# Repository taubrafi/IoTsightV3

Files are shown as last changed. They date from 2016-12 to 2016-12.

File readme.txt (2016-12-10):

IoTSights Project:
	
	Case --Solidworks files for enclosure

	CC3200_workspace
		{Lots of files}	--	Lots of test/old stuff
		ProjectV3 		-- 	main project files
			ADXL345		--Code for accelerometer (interrupt never implemented)
			DS2401		--Code for hardware ID chip
			GPS			--Turn GPS on and off
			HMC5883		--Code for compass (with callibration)
			IMU			--Math to calculate orientation angles
			main		--main
			MPL115A2	--Code to read form barometer and convers to kPa
			NetworkFunctions	--HTTP/Server functions
			NMEA				--Code to decode the GPS information
			parameters			--a few defines and paramaters
			pinmux2 (pinmux ignored)	--pin setup
			SD_card						--Code to write to SD card (not implemented fully)
			SimpleLinkFunctions			--Code to connect to Wi-Fi network 

	OLD project files 	-- report/presentation documentation
		
	PCB					-- PCB files (eagle)
	
	IoT_Sight_FULL 		-- Full schematic for PCB (pdf)

To get up and running:
	Install the latest version of CCS according to the TI website for the CC3200.
	Install Uniflash CC3200_sdk and servicepack (all folowing TI directions exactly)
	See:		https://www.youtube.com/watch?v=xbh9I8waq5g
	Or search: 	"SimpleLink Wi-Fi CC3200 Project 0: Code Composer Studio IDE"

You're ready to go

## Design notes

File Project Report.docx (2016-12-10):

Cover page….

# Abstract

The problem of relaying battlefield information is at the heart of all modern warfare, getting crucial, reliable data from one area to another, or from the battlefield back to the chain of command as fast as possible.

To help mitigate the problem, we developed a small, lightweight, gun mountable sensor array with wireless capabilities and sufficient battery life to record and transmit vital information off the battlefield. In addition, an off-site server will process and display the information, and could be used to alert necessary personnel if need be. The system could also play a role off the battlefield, simplifying the tracking of weapons, automatically calling for backup in sudden life-threatening situations, or to assist training exercises.

# תקציר

בעיית העברת מידע אמין משדה הקרב היא בעיה מרכזית בשדה הקרב המודרני, העברת מידע אמין וחיוני מאזור קרבות אחד למשנהו, או משדה הקרב חזרה לשרשרת הפיקוד במהירות האפשרית. כדי לנסות ולמזער את הבעיה פיתחנו חיישן קטן מימדים וקל משקל להתקנה על הנשק, בעל יכולות אלחוטיות וחיי סוללה מספקים על מנת להקליט ולשדר מידע חיוני משדה הקרב. בנוסף לכך, שרת הנמצא מחוץ לאזור הקרבות יעבד ויציג את המידע המתקבל ויכול לשמש להתרעת כוחות שונים במידת הצורך. בנוסף לכך יכולה מערכת זו לבוא לידי שימוש גם מחוץ לשדה הקרב, לפשט את המעקב אחרי נשקים, הזעקת גיבוי באופן אוטומטי במצבים של סיכון חיים, או לסייע באימונים.

# Table of Contents

# Table of figures

This needs to be updated manually after adding images with captions. Under references->Update table: Ctrl+A F9

# Table of symbols and abbreviations

GPS – Global Positioning System

GLONASS – Global Navigation Satellite System (Russian GPS system)

Li-ion – Lithium ion battery

Wi-Fi – Wireless fidelity (wireless network connection)

PCB – Printed Circuit Board

RF – Radio Frequency

MCU – Microcontroller unit

SPI – Serial peripheral interface

IC – Integrated circuit

I²C – Inter-Integrated circuit communication protocol

SMD – surface mount device

LGA – Land grid array

BGA – Ball grid array

I/O – Input and output

MEMS – Micro-electrical-mechanical system

VCC – Supply voltage

GND – Ground (voltage return)

PLA – Polylactic acid (a plastic)

TI – Texas Instruments

ATM – Automatic teller machine

AWS – amazon web services

ec2 – elastic cloud computing

HTTP – hypertext transfer protocol

SSH – secure shell

OS – operating system

# 1 Introduction

## 1.1 System purpose

The system consists of two separate sections, a physical unit, distributed to each soldier and mounted to the weapon, and a server to collect and process the data.

The unit is always running, but remains dormant most of the time to conserve battery life. When a soldier fires his weapon, the weapon experiences a sudden change in acceleration along its axis, known as ‘recoil’. The device’s accelerometer captures this sudden change in acceleration and causes an interrupt to wake up the processor. The processor then takes a snapshot of all current sensor data and preprocesses it to extract the devices orientation, heading, altitude and position, and the time of the occurrence. This information, along with the devices unique ID number, is sent via Wi-Fi to the main server, which displays the information on an interactive map. Depending on requirements, the server could be setup for multiple purposes. In one instance, it could be used to take multiple shots’ information to predict where enemies might be and automatically notify other soldiers in the area that assistance is necessary. The server could also be setup as part of training exercises, and would be used to analyze how many shots each participant fired and how accurate each shot was. The device could also be mounted to steel plate targets to detect when a ‘hit’ occurred.

## 1.2 Physical Unit

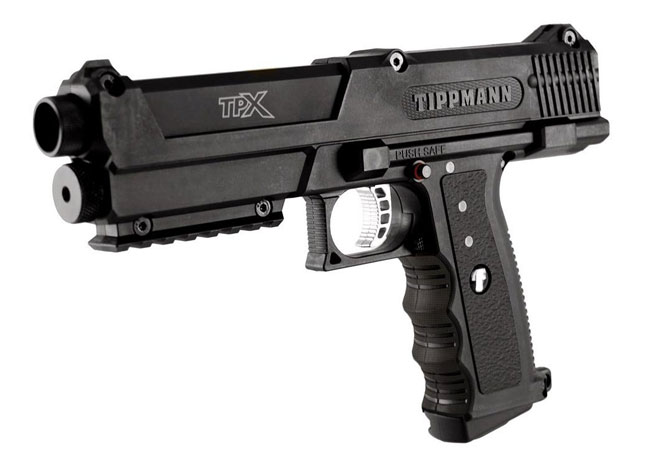
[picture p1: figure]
Image result for picatinny rail paintball

The physical unit is a small plastic enclosure not much bigger than a can of soda and weighing ~???g. It can be mounted to nearly any weapon via a standard ‘Picatinny rail’ mounts which are commonly used for mounting accessories to a weapon such as scope sights, lasers, and flashlights (see Figure 1). These are present on nearly all military issue weapons ranging from pistols to large machine guns.

Figure 1: Picatinny rail on a paintball pistol

The unit is a sensor array consisting of the following:

- Accelerometer
- Gyroscope
- Magnetometer
- Barometer
- GPS receiver

Together, they give the ability to read out orientation, altitude, and location in the form of roll, pitch and yaw angles, GPS coordinates and ambient air pressure. The accelerometer also gives the ability to send out an interrupt on sudden changes in acceleration along any axis, which is used for the shot detection function.

The plastic enclosure houses the battery and main PCB, and can be sealed against water and dust while still providing a pressure relief port to take accurate air pressure measurements.

The battery is a standard sized Li-ion cell, which can be swapped out for charging. The idle battery life is just over 21 days, and each shot detection and transmission taking up to 30 seconds expends the battery life equivalent of up to 6 minutes of idle time.

## 1.3 Server

The server is a virtual machine provided by amazon as part of AWS. In the service, it is often called an instance of ec2. That means that the consumer is provided with a computation power and internet connectivity without having to buy hardware, Thus enabling a low cost server farm to be used while enjoying robustness huge scalability and few locations redundancy for mission critical solutions.

The virtual machine is configured to run Ubuntu a distribution of linux that is used both in commercial and private settings. The http server is apache, it is the means by which the HTTP requests are served so that users could connect to the webpage. The webpage itself has a dynamic rendering that creates an html view according to the queried parameters. The language used to create the dynamic interaction is python, namely the django library of the language. Data from devices is stored in sqlite3. Map rendering is made with a google maps API in javascript. There is also an xml static page served for the devices to read periodicaly to change their state to close a control loop.

xml | Images | Css | javascript | Html
Static files | | Django app
Apache web server | | | sqlite3

Ubuntu linux

AWS amazon cloud compute

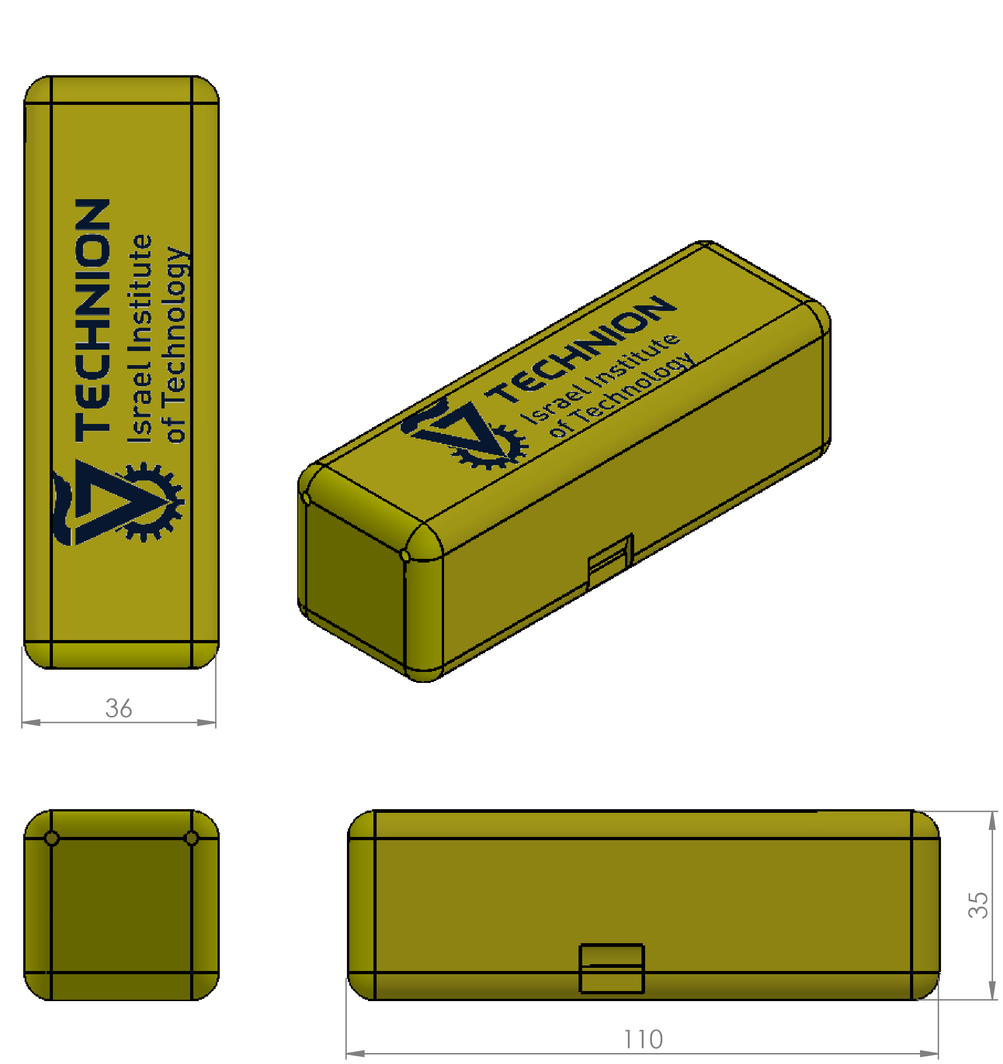
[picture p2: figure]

# 2 Specifications

Figure 2: Device physical dimensions

## 2.1 Physical Specifications

PARAMETER | | UNIT
Length | 110 | mm
Width | 36 | mm
Height | 35 | mm
Weight | 120 | g
Operational Temperature range | -40 to +85 | °C

## 2.2 Electrical specifications

PARAMETER | | UNIT
Battery Type | 18650 Li-ion | -
Battery Voltage | 3.5 to 4.4 | V
Battery Capacity | 2200 | mAh
Idle current | 4.3 | mA
Idle battery life | 21.3 | day
Transmitting current | 54 | mA
Continuous transmission battery life | 40 | hour
Peak current | 250 | mA
Maximum time to transmission | 30 | second
Roll accuracy | ±1.0 | degree
Pitch accuracy | ±1.0 | degree
Heading accuracy | ±2.0 | degree
Position accuracy | 10 | m radius

## 2.3 Server specifications

The server is a t2.micro instance with the following specs:

Vcpus | 1
RAM | 1Gb
HDD | 8Gb
OS | ubuntu

We are using apache2. Python 2.7 . Django 1.9 . slqite3.

# 3 Workflow

## 3.1 Hardware

MCU

[CC3200]

Accelerometer

[ADXL345]

Wi-Fi

[CC3200]

Magnetometer

[HMC5883L]

Gyroscope

[ITG3200]

GPS

[NEO-6M]

SD card

Support Hardware

Figure 3: Hardware block diagram

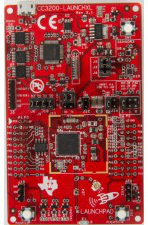
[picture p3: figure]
Image result for cc3200 development kit

### 3.1.1 Component choices

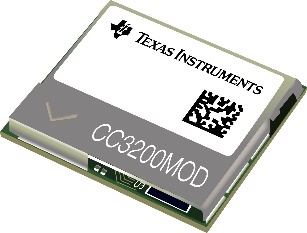
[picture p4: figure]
Image result for cc3200mod

The first major component is the MCU, which serves as the processor for the hardware. For this purpose, the CC3200 chipset from TI was chosen. This was because it has built-in Wi-Fi capabilities which require no external components aside from an antenna. This greatly reduces the amount of design work that falls into the RF spectrum which requires a great deal of additional experience. The CC3200 is available in two forms, the first, a SMD chip, which needs various support components such as decoupling capacitors, pullup resistors, crystal resonators, and an SPI flash memory chip. The second form is a module which has all the above components build into a SMD LGA package of 17.5mm x 20.5mm. Due to cost and ease of use, the chip form was used during development while the module was used on the final PCB. The MCU also feature a hibernate mode where current consumption drops down to 4uA while still allowing for external interrupts to ‘wake up’ the MCU. This choice also eliminates the need for an external wireless chipset which also conserves power since readily available Wi-Fi modules such as the ESP8266 use more power even when in hibernation modes.

Figure 4: CC3200 module

Figure 5: CC3200 development kit

For an accelerometer, the ADXL345 was chosen for its low power consumption, easy to solder package (LGA as opposed to BGA) and its dual configurable interrupt outputs which were used for the ‘shot detection’ feature. The interrupts are configurable to only capture motion along a single axis and to fire only when the acceleration exceeds a configurable magnitude. The data can then be read out over an I²C interface.

The HMC5883L was chosen as the magnetometer the device for the same reasons that it’s very popular in the hobbyist community. It has low power consumption, simple I²C interface, and easy to solder SMD package.

A gyroscope chip, the ITG3200 was also included in the design, although it isn’t necessary for the intended application of the device and the component does not need to be inserted during manufacturing. Its pads however are present on the PCB, which enables various other applications and uses for the device as will be mentioned later.

Because of time constrains and availability, the NEO-6M was chosen as the GPS module for the device, since it was already on hand.

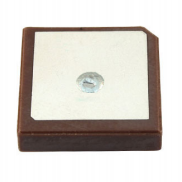
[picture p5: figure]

Since the unit will be oriented in a specific direction and the GPS satellites only ever being above any point on earth, the antenna for the GPS could be a directional antenna, which would provide gain to the GPS signal, and in turn, greater accuracy in position measurements. Since the output impedance of the CC3200 is 50Ω, it was easiest to find an antenna which also had an impedance of 50Ω. In addition, the device required a rather thin profile which lead to the choice of a ceramic patch antenna. The ADA18182 was chosen for this since it is easy to solder and for its small size of 18mm x 18mm and 2mm height.

Figure 6: ADA18182 ceramic patch antenna

Again, due to time constraints and availability the MPL115A was chosen as the barometer for the device to give more accurate altitude measurements than the GPS system can provide. The ‘A2’ version of the chip was used since it interfaces via I²C as the other sensors do and therefor doesn’t require additional I/O pins.

The last major component is the DS2401+ which is a silicon serial number. It provides a unique 64-bit identification number hard coded into the device (which gives 18 billion-billion unique ID numbers). Since no two chips have the same number this enables individual tracking of every device and the ID number can be matched with every issued weapon and individual using it. This device also has a ‘OneWire’ interface which only requires one additional I/O pin. (The chip only has two pins, ground, and data. There is no positive voltage line, instead the chip charges an internal capacitor from the pullup resistor on the data line and uses that stored charge to continue operating when the data line is low.)

In addition to the above, various other components such as capacitors, resistors, LEDs, a transistor, voltage regulator and a microSD card socket were included in the design. The microSD card connector was included for future expandability and as with the gyro, does not play a role in this application.

### 3.1.2 Electrical design (schematic)

The schematic design is rather straightforward, all the integrated circuits were connected with the necessary external components as per the manufacturer’s specifications. In addition, decoupling capacitors were placed near each IC. A removable solder jumper was added between the DAT1 pin of the SD card and GND. This enabled the switching of SD card protocols during the debug stage. In the end, the ‘SPI mode’ of the SD card was chosen, meaning the jumper can be left as is (connected to GND).

To conserve power, a PNP transistor was connected between VCC and the GPS receiver’s main power input pin while the backup battery input was left connected to VCC. This enables the shutdown of the GPS receiver to be controlled by the microcontroller while keeping the GPS data in memory. This ensures a faster ‘hot fix’ when trying to regain the location data from the GPS system.

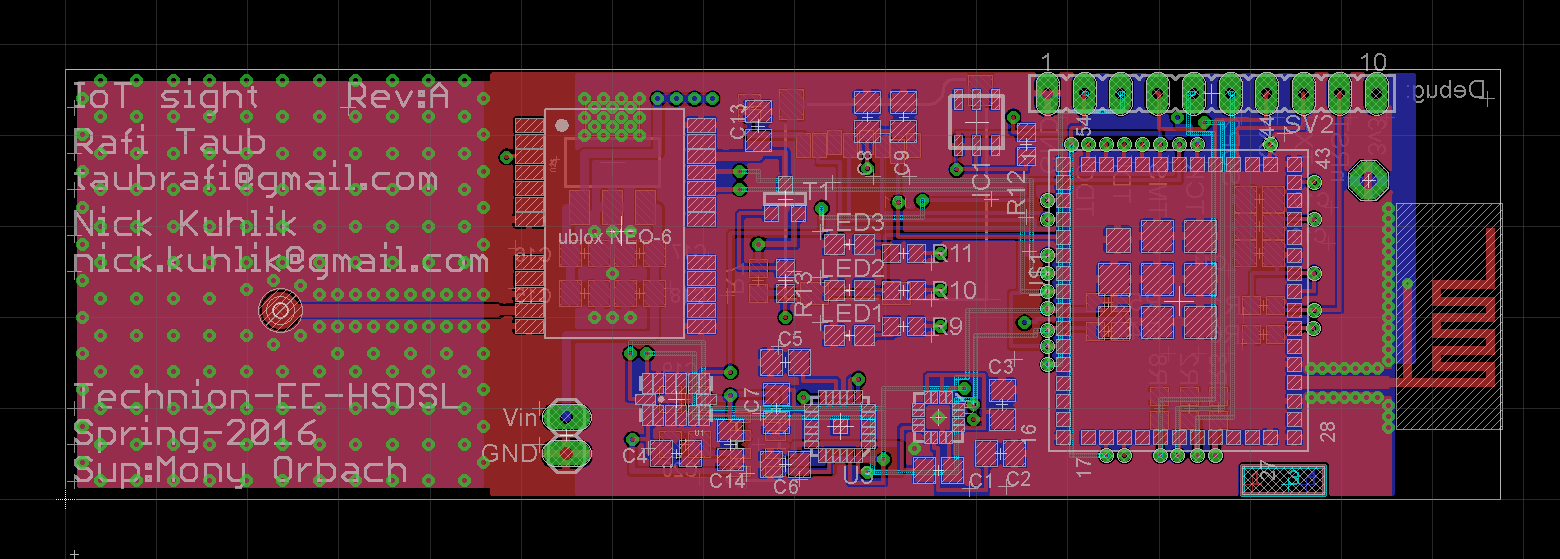
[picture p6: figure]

### 3.1.3 PCB design (layout)

The PCB was designed using EAGLE which is a combined schematic and layout software which is supported by most PCB manufacturers.

The PCB has four layers which are (from top to bottom): Signal layer with ground plane flood, supply voltage plane, signal layer, signal layer with ground plane flood. Although the system performs as expected the two internal layers should have been voltage supply and ground, with all signals kept on the outer layers. This would increase the distributed capacitance across the entire board keeping noise to a minimum. It would also keep a solid ground plane below signal traces keeping impedance constant and minimizing wave propagation artifacts caused by reflections. However, since all signals (excluding the RF areas which have no internal layers) in the device are rather slow (less than 1MHz) we did not experience any issues.

Figure 7: The device PCB in EAGLE

Three LED indicators were added at this stage (as can be seen in the center) and were connected to three spare I/O pins on the CC3200. They were meant as aids during debugging and are not mean to serve any function in the final version. That said, as with the gyro and SD card could be used in possible future applications for the device.

The three MEMS sensors were placed so that all their axes are aligned to keep data processing simple, and a debug header is also present to enable programming of the CPU without the need for desoldering. It also provides a serial terminal for printing debug messages and data (again, for use during debugging). Two battery voltage input pins are also present.

Lastly, ‘open vias’ we placed on all signal pins to enable probing, and cutting-resoldering of traces as needed when working on hardware. To aid in probing, one more large ‘via’ was added and connected to the ground plane as a reference for oscilloscopes and logic analyzers

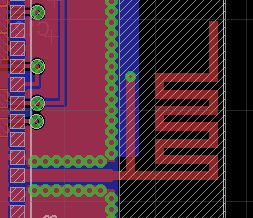
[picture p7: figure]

### 3.1.4 RF and antenna design

The last two key components on the PCB require special attention. The Wi-Fi antenna was designed as part of the board while the GPS antenna is a ceramic patch antenna. Both require specific dimensions in both the traces that connect them and the ground plane below them.

Figure 8:Wi-Fi antenna close-up

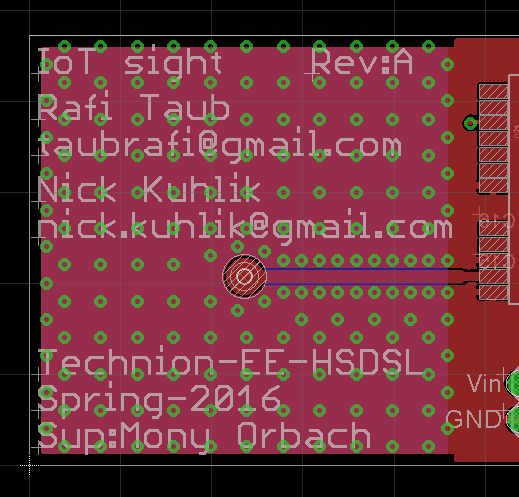
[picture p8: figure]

The design for the Wi-Fi antenna was taken from an application note[^1] from Cypress semiconductors on Wi-Fi and Bluetooth antenna design. The PCB antenna choice was made to since it doesn’t require a matching network to convert to a 50Ω trace. It also provides reasonable directionality, sending the signal out along the plane of the PCB instead of normal to the PCB, which would be directed into the battery. This effectively adds gain to the signal being sent back to the router which is receiving the signal adding range to the unit’s operating radius. In addition, the trace connecting the antenna to the CC3200 is of a specific width with the ground plane coming to a specific distance away from the trace. This trace setup is known as a ‘coplanar wave guide’ and is commonly used for signals in the few up to tens of GHz range.

For the GPS antenna, the dimensions for the ground plane were taken from the device’s datasheet. The ground plane gives then antenna directionality and therefore gain (of about +5dB) in the upward direction normal to the plane of the PCB. This improves positional accuracy, likelihood of GPS lock, and time to lock for the GPS receiver. The trace connecting the GPS antenna to the receiver is also a ‘coplanar wave guide’ and has the same dimensions as the Wi-Fi trace since the GPS signals are in the same band being ~1.5GHz.

Figure 9: GPS test antenna

Figure 10: GPS antenna close-up

During development not all the components had arrived, so for testing a dipole antenna for the GPS was desinged and added as part of the PCB sent to manufacturing. Although it does work, the ciramic antenna is a better choice for its directionality and low losses.

### 3.1.5 Mechanical design

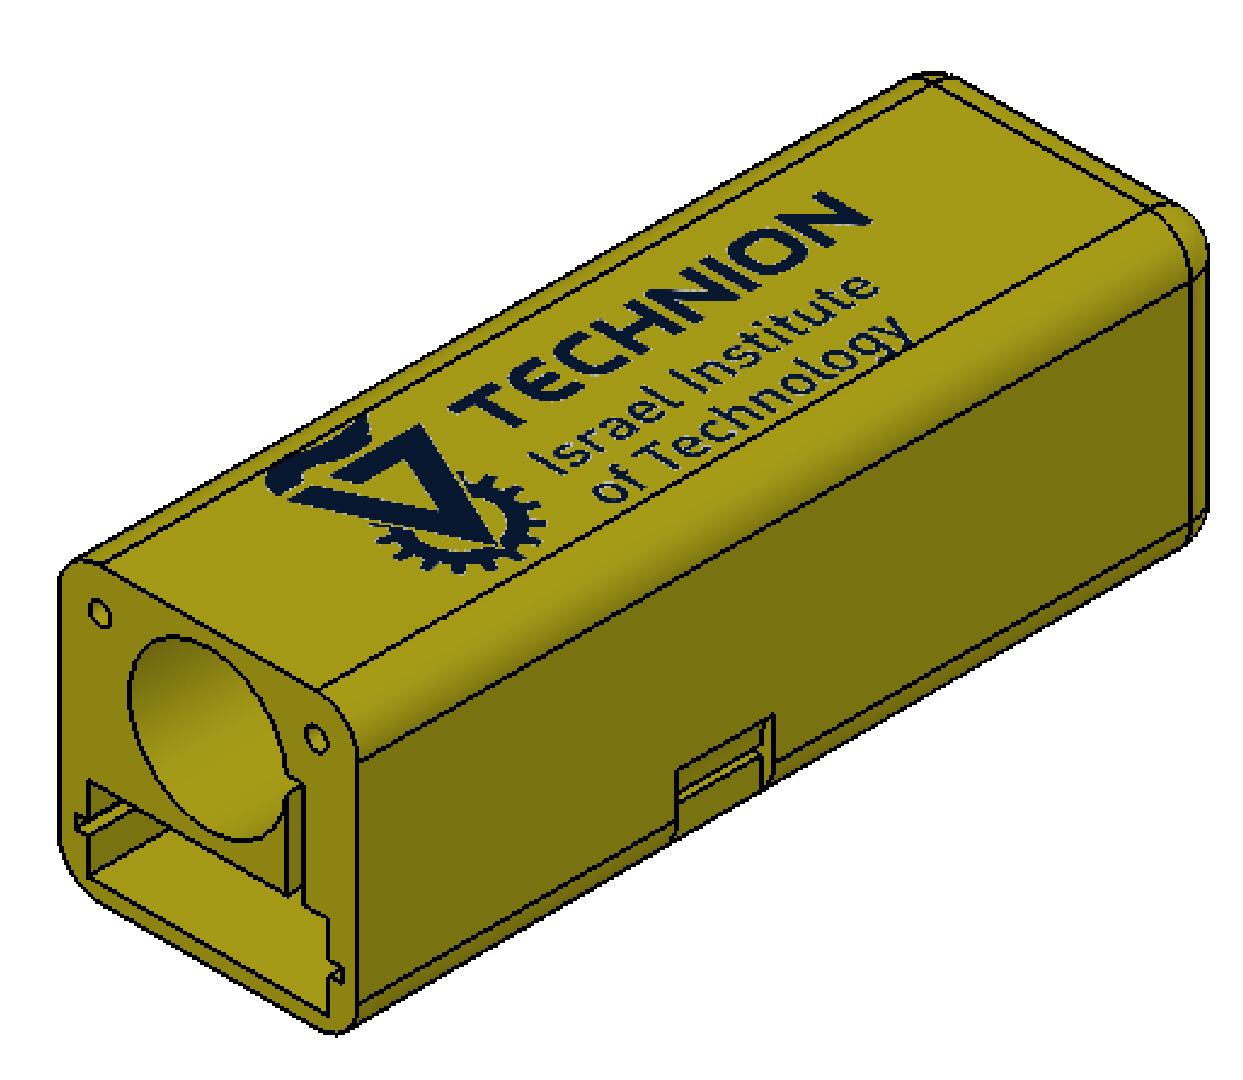
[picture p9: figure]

The devices prototype enclosure is a 3D-printed PLA which was designed in SolidWorks. It features a slot for the PCB and a compartment for the battery. The battery was chosen to be an 18650 Li-ion rechargeable battery with a nominal voltage of 3.7v-4.2v and a capacity of 2200mAh. The slot along the side of the battery cutout is for the wire running to one of the terminals. Both wires run down into the lower compartment to the main PCB. In addition, a slot on the side of the enclosure gives access to the microSD card and lines up with the socket on the PCB. The alignment was maintained by taking measurements from the PCB and bringing them into SolidWorks to make the required cuts. A rubber cap could be designed to cover this hole to provide weatherproofing while still allowing changes in air pressure through to the internal barometer. The cover attaches to the case by two #4-40 screws which rotate freely in the cover and screw into the slightly undersized hole in the main body of the enclosure to ensure a solid connection. The last part of the enclosure not show in this diagram is a mount to connect the device to the Picatinny rail system for mounting on a weapon.

Figure 11: Device enclosure

## 3.2 Firmware

Figure 12: Firmware flowchart

Calibration routines

Sleep

Power on sensors

Read sensor data

Calculate altitude & attitude

Get position from GPS

Power off sensors

Accelerometer triggered interrupt

Send data to server

### 3.2.1 Orientation algorithm

Once a shot is fired the accelerometer triggers an interrupt on the MCU which prompts it to turn on the GPS module and proceed to take readings from the various sensors. From the corrected magnetometer data (B_(fx) ,B_(fy) , B_(fz) ) and the accelerometer data (G_x , G_y , G_z ) .

First the roll angle ϕ is calculated as:

ϕ=atan2(G_y , G_z )

(Note the atan2(y,x) function provides the inverse of tan(⋅)=y/x where the signs of x and y are maintained, giving a result on [-π,π] instead of [-π/2,π/2] .)

Next, the pitch angle θ is calculated as:

θ=atan(-G_x , G_y sinϕ+G_z cosϕ)

(Not atan2(y,x) since the pitch angle should lie on [-π/2,π/2] .)

Lastly, the yaw (heading from magnetic north) angle is calculated as:

ψ=atan2(B_(fz) sinϕ-B_(fy) cosϕ, B_(fx) cosθ+B_(fy) sinθsinϕ+B_(fz) sinθcosϕ )

Together these three angles give a complete description of how the device (and therefore the shooter) is oriented at the time of the occurrence.

### 3.2.2 Magnetometer Calibration

As mentioned, the magnetometer data is used to calculate the orientation angles of the device and the equations rely on the magnetometer data (B_x , B_y , B_z ) however, this data is not usable directly as magnetic offsets are a major problem with magnetometers. Any piece of ferrous metal (steel, iron, etc.) all have slight magnetizations and will offset the magnetometer readings.

If each data reading from the magnetometer were to be plotted on a graph while the device was rotated to every possible orientation, the points would form an ellipsoid with axis lengths of (l_x ,l_y , l_z ) in the x, y and z directions respectively and the center of the ellipsoid would be at (p_x , p_y , p_z ) . Ideally, the center of the ellipsoid would be at (0, 0, 0) and the axis lengths would all be equal (1, 1, 1). However, small magnetized objects will both shift the center of the ellipsoid along the axis the magnetic material points, and lengthen or contract the respective axis depending on the alignment of the material. This could be potentially catastrophic as a flat north-facing orientation, which would ideally give a magnetometer reading of (1,0,0) would be could be shifted and scaled to give any possible reading (a reading of (-1,0,0) would mean south). To counter this, a simple calibration algorithm was added to the software, which works as follows:

- Six static values are stored which represent the lowest and highest recorded values (the ‘extreme values’) on each of the magnetometer’s axis respectively. (X_m , X_M ),(Y_m , Y_M ), (Z_m ,Z_M )
- On each reading, the current value is compared with the stored extreme values, and the extreme values are updated as needed.
- We then define: p_x =(X_m +X_M)/2 , p_y =(Y_m +Y_M)/2, p_z =(Z_m +Z_M)/2 . Since an ellipsoid is symmetric with regards to any of its axes, its center must be halfway between its two ends. Thus, we know where the center of this offset ellipsoid lies.
- Next, we define: l_x =X_M -X_m ,l_y =Y_M -Y_m ,l_x =Z_M -Z_m which represent the lengths of each of the axes of the offset ellipsoid.
- Lastly, B_(fx) =(B_x -p_x)/(l_x), B_(fy) =(B_y -p_y)/(l_y), B_(fz) =(B_z -p_z)/(l_z) This shifts the ellipsoid back to (0, 0, 0) and brings then axis lengths back to (1, 1, 1).

This algorithm is essential in maintaining good orientation data accuracy. One of its main benefits over pre-calibrating each device is that this algorithm is a very simplistic ‘machine learning’ algorithm. To initially calibrate the unit, one simply needs to rotate the unit a few times in each direction, and once mounted to the weapon the offsets would change since the weapon itself contain many metal pieces. Even the bullets or magazines could be magnetic and since they are swapped out regularly, it would mean any possible pre-calibration would be useless. But with this algorithm, one needs to just power cycle the device (by swapping the batteries) and rotate the device while attached to the weapon to recalculate the calibration values.

### 3.2.3 Issues with I²C, Wi-Fi startup and z axis magnetometer data

During the development stage, several interesting issues were uncovered which are worth mentioning since their cause was not due to any development error on our part but rather on the manufacturers of some of the components we used. Two such issues were found in the CC3200 manufactures by Texas Instruments. The CC3200 was a relatively new device at the time when development started and as with many new devices, it had some issues that had not yet been found. The first of which was had to do with the assignment of I/O pins used for I²C communications. To save pins on the device package, the two I²C pins can be mapped to several physical pins on the device, but only two such physical pins can be assigned for this purpose. It turned out the device had a predetermined assignment for these pins which was not noted in the datasheet and the assignment had to be undone before reassignment could be performed. A few weeks after we found the issue, a relevant section was added to the CC3200 errata sheet on TI’s website. A similar issue was found in the startup code for the Wi-Fi communications on the CC3200 and was later corrected with a library update by TI.

The last notable issue was not a software bug but rather a hardware defect. As it turns out, the HMC5883L chips which we purchased for use in the early design stage were not manufactured by Honeywell, but instead were manufactured by some copy facility in china. These ‘copy chips’ were not as robust as the originals and the Z axis sensor head inside the chip would fail and only gave constant data. Once the problem was discovered, some genuine chips were ordered which worked flawlessly.

### 3.2.4 Get request

The very last step in the data path for the device is the ‘Get request’ sent over the Wi-Fi network connection to the server. The request is formatted to have separate fields in a predefined protocol setup for this system and transmits: the current date and time, the devices latitude and longitude, the ambient air pressure (used in conjunction with weather servers to calculate altitude), the device’s orientation angles, and the device’s unique ID number.

# 4 Software (server)

## 4.1 Architecture

xml | Images | Css | javascript | Html
Static files | | Django app
Apache web server | | | sqlite3

Ubuntu linux

AWS amazon cloud compute

The architecture selected for the server was guided by the principles of simplicity, scalability and reliance on free open source software.

By implementing those principles it is guaranteed that the project will be easy to maintain and easily passed to future generations of students. The

TODO:

here goes explanation about the idea to make a mono-core of code that uses python.

Google maps api addition. Since we didn’t want to roll out our own maps.

## 4.2 AWS

The aws platform gives a readily made instance of a computer that can be easily replicated to adjust for demand. The servers are located In data-centers separate from each other thus granting fault tolerance in case of a local disaster that disables one of the locations. Also, it is easier to rent a server on the web and route all traffic to it instead of aquiring a pc to be used in the technion network and having to open up connections to the internet and managing the hardware. A fault that was critical to another project in the HSDL lab.

In conclusion, the aws platform is both convenient for both small scale deployments that don’t necessitate the purchase of additional hardware and large scale mission critical deployments.

## 4.3 Ubuntu

Ubuntu is free open source linux distribution targeted both for the private and corporate use. The distribution is well supported and well documented with a vast community of developers using the OS.

The ubuntu os takes care of the lower levels of the OSI hierarchy registering the pc on the network, creating sockets and collecting ip packets into a tcp protocol.

Also, the ubuntu machine runs the application and saves the database giving useful tools to manage and edit both.

## 4.4 Application

the application is constructed upon the interaction of a database, a collection of static resources that are not need to interact with the server in a dynamic way , and a python application that controls the database workflow, fetches static files, renders dynamic views for the user and interacts with the thin client implemented on the tracked unit.

## 4.5 sqlite3

sqlite is a relational database used to create read update and delete records in a SQL way that makes a standardized way to work with data. This way was chosen because it is easily used, although it may be switched for any preferred database with little effort.

The application generates the needed data tables in accordance to the models that are described in the application code. The data is then easily saved and retrieved and can be accessed both from the python wrapper for sqlite3 and a mysql like command line tool.

The sqlite3 is pointed back to the hosting machine, but in future versions can be shared with several machines hiding behind the DMZ in the internal firewall. This configuration can be useful for decoupling database and apps for robustness and scalability.

## 4.6 Apache*

The apache web server manages connections on the http level, after a connection has been established by the linux os, the http web server must direct the user to the appropriate location and gather the data needed from the application to return.

The apache web server was chosen for its free as in free beer ideology and great swath of support.

## 4.7 django

Django is a full stack web framework written in python that is used to control the layer 7 application interaction with server. The framework is a set of modules written in python that make prototyping websites faster and easier by taking care of the stuff that usually all web servers must preform and giving capabilities to write code that will do the “Buisness Logic” of the application.

The application is created in the mvc design pattern which separates the problem into 3 components.

The central component of MVC, the model, captures the behavior of the application in terms of its problem domain, independent of the user interface.

- The model directly manages the data, logic, and rules of the application.
- A view can be any output representation of information, such as a chart or a diagram. Multiple views of the same information are possible, such as a bar chart for management and a tabular view for accountants.
- The third part, the controller, accepts input and converts it to commands for the model or view.

In our app, the model -represent the shots class and its methods.

The view – is the /shots page that prints the output.

The controller is the url parser that directs the user to the page requested (view) showing the data selected (model).

## 4.8 google maps api

Using the javascript api, the google maps api is useful for visualising the received points of interest and bearings to the user that shall interpret them. It is possible to use javascript additional functionality and create algorithms for crossfire enemy detection based on time and location, friendly fire alarms and training situations in which part of the sensors are designated static targets. Also we can show different slicing of data, by time period or location specific and even create a “recording” of events that shall be useful in debriefing missions or training excercises.

## 4.9 xml gateway

The xml gateway is a useful format to push data back into the tracking device’s memory. Since each unit is arbitrarily woken up and may experience connection loss or be given a dynamic ip, there has to be a way to update the settings that govern the devices. The best way is to point them to a known location available when connection to transmit data has occurred. The xml page contains the id and data settings that need to be parsed by each device. The xml page in the prototype is a dummy place holder and has no receive functionality on the devices (as of writing of this project report it was deemed useless for the means of this configuration). The django app can and should create a the xml file in accordance with the logic decided upon.

## 4.10 server issues at deployment

After creating the application on a local machine, the migration process was to upload the files into an ec2 instance from the github repository.

On the local machine an Internet port serving only the localhost is generated once the app is run. Once the app is deployed a web server (like apache) has to commandeer access to the requested ip and pass them to the app.

In the development process a problem was encountered that only part of the webpage would load without additional styling. Thus giving a plain look to pages that were stylized before the deployment.

Since it was chosen to host the static files locally, the app had to look up the files on the hard disk and send them to the user to generate an HTML. The problem has been diagnosed as a permissions denied response when requesting those static files. A number of fixes to try and change file permissions were tried, changing locations, owners, privileges and such.

The problem was at last solved by a technical document describing the proper apache configuration to enable a static folder to become world available and thus hyperlinked to the HTML file, rendering it completely.

The main takeaway from this problem was that although there is great support for apache, a problem with django which was still young at the time was not identified correctly due to not informative errors and then hard to fix since the django-apache stack was new at the time.Performance tests

# 5 Extensions and additions

This system has many more possible applications that the original intended purpose. The physical unit is essentially just a Wi-Fi connected sensor module with GPS and datalogging which could be used for inventory or vehicle tracking, amateur rocket experiments, long term datalogging, earthquake detection and much more. In addition, the I²C and SPI interfaces, along with the remaining I/O pins could be used to connect further external sensors or as outputs to trigger alarms, lights, motors, or anything else. Combined with the small form factor this device could even serve as the heart of an autonomous drone and could in theory support a low-resolution camera and transmit back over Wi-Fi.

One addition that was left out of the project due to time constraints and practicality is encryption. It wouldn’t be very smart for every soldier to transmit his location over a Wi-Fi connection, since any laptop running Wireshark (a free network traffic analyzer tool) could simply read out the data and track down the soldiers. Therefore, a layer of encryption would be necessary to hid the data from anyone who could try to read it. This encryption would have to be implemented on both ends, the device, and the server, and must be done in such a way that even if a potential enemy gets hold of one of these devices, he still would not be able to break the encryption. Solutions like this are quite common in the software industry and it’s how activating a piece of software with a license key is simple and yet it’s impossible to somehow find out what possible license keys the software would treat as valid even if you have the software installed.

Another feature that could be added to avoid the above issue is a remote self-destruct, where the microcontroller could wipe its own flash memory and reset itself (doing nothing from then on unless reprogramed) if the PCB area of the enclosure is opened or by remote signal (a technique used in cred card readers and ATMs to prevent bank fraud).

# 6 Source code

Device firmware and project files: https://github.com/taubrafi/IoTsightV3

Server source code: https://github.com/sudo-Whateverman/IOTsights

# 7 Appendix

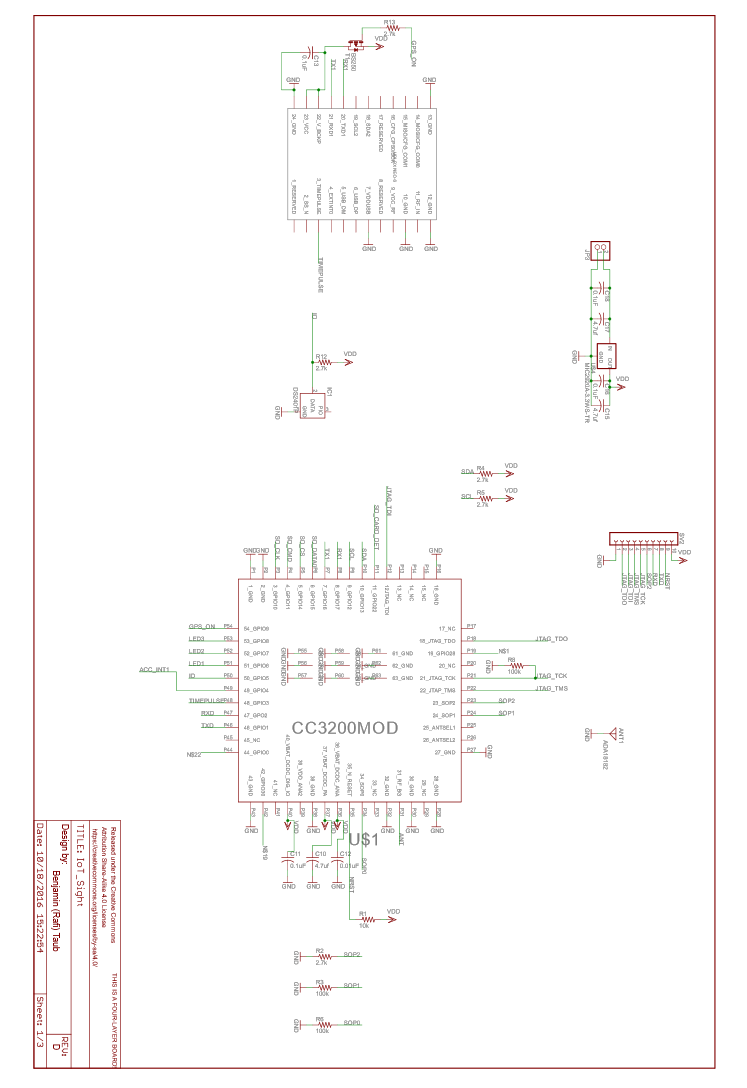
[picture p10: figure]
Machine generated alternative text: GNDGNDGND GND GND GND GND GNDGNDGND GND GND GND GND GNDGND GNDGND 10k 2.7k 100k 100k GNDGNDGND VDD VDD VDD VDD 2.7k 2.7k VDD VDD GND GND GND GNDGND 4.7uf 0.1uF0.01uF GND GND GND 100k GND GND VDD DS2401P GND 2.7k VDD 0.1uF ADA18182 GND MIC2920A-3.3WS-TR VDD GND 4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

## 7.1 Appendix A: Full electrical schematics

Figure 13: Electrical schematic page 1 of 3 (main MCU and GPS)

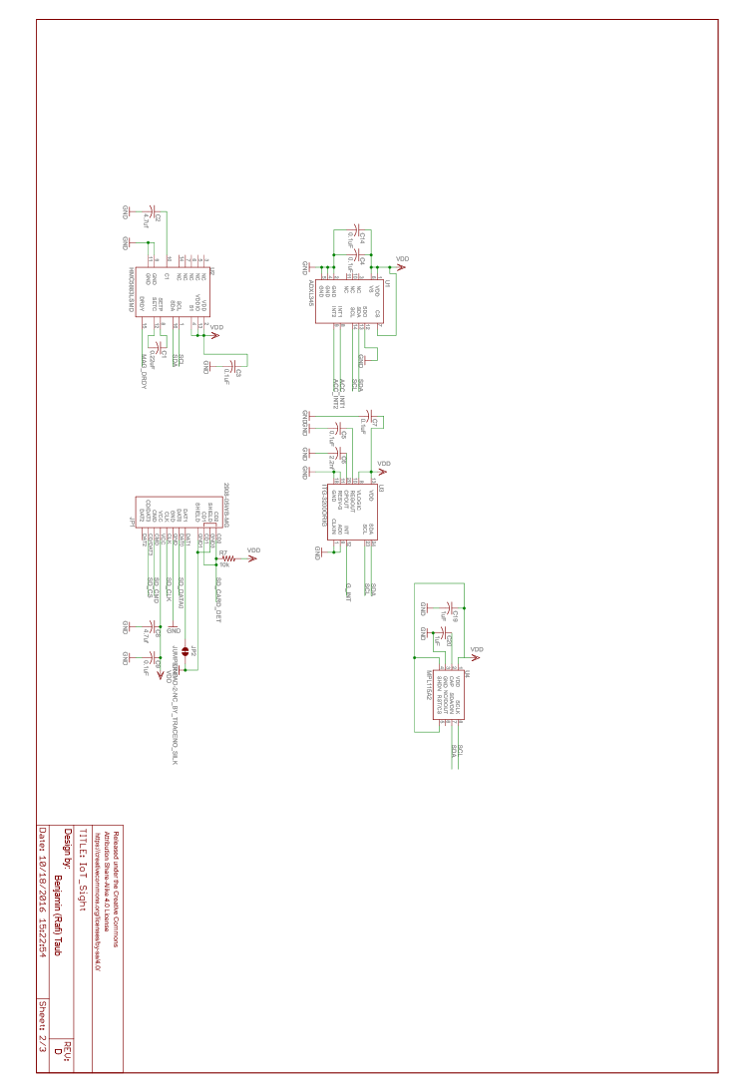
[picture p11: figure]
Machine generated alternative text: ADXL345 HMC5883LSMD ITG-3200ORIG 2908-05WB-MG VDD GND VDD GND GND VDD GND 0.22uF 4.7uf GND 0.1uF GND 0.1uF GND 0.1uF2.2nf 0.1uF JUMPER-PAD-2-NC_BY_TRACENO_SILK GND 10k VDD VDD GND 4.7uf0.1uF GNDGND 0.1uF MPL115A2 1uF 1uF VDD GND GND GND GND GND U1 VDD 1 NC 11 NC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

Figure 14: Electrical schematic page 2 of 3 (sensors and SD card)

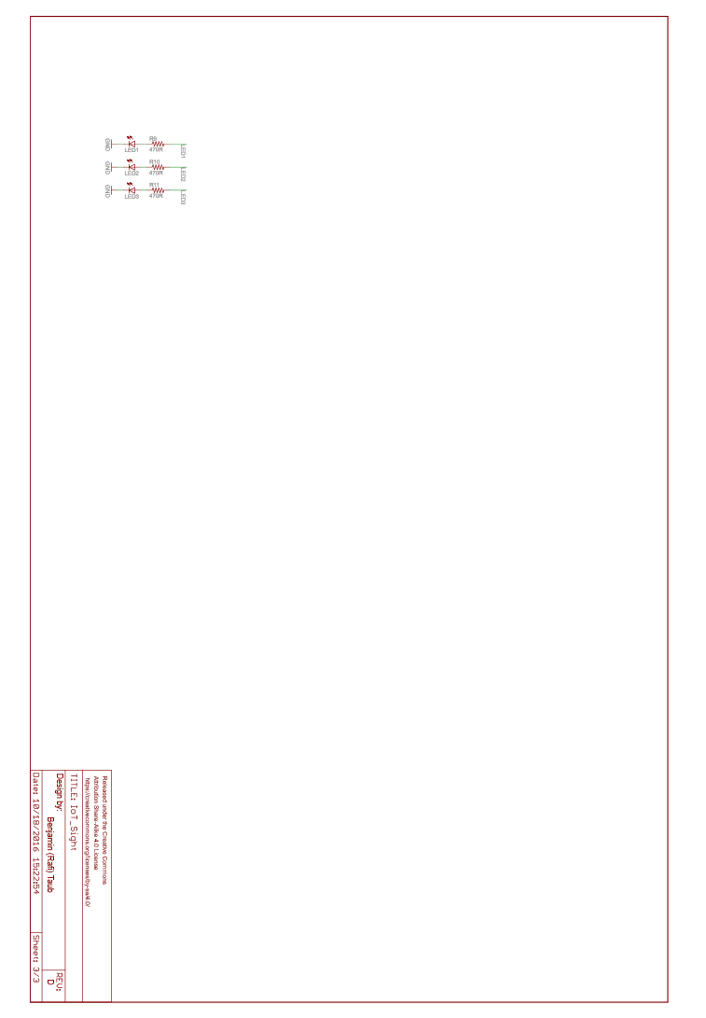
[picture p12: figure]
Machine generated alternative text: 470R 470R 470R GND GNDGND LED1 LED2 LED3 R9 R10 R11 LED1LED2LED3 D Benjamin (Rafi) Taub Released under the Creative Commons Attribution Share-Alike 4.0 License https://creativecommons.org/licenses/by-sa/4.0/ Design by:

Figure 15: Electrical schematic page 3 of 3 (LED indicators)

## 7.2 Appendix B: PCB

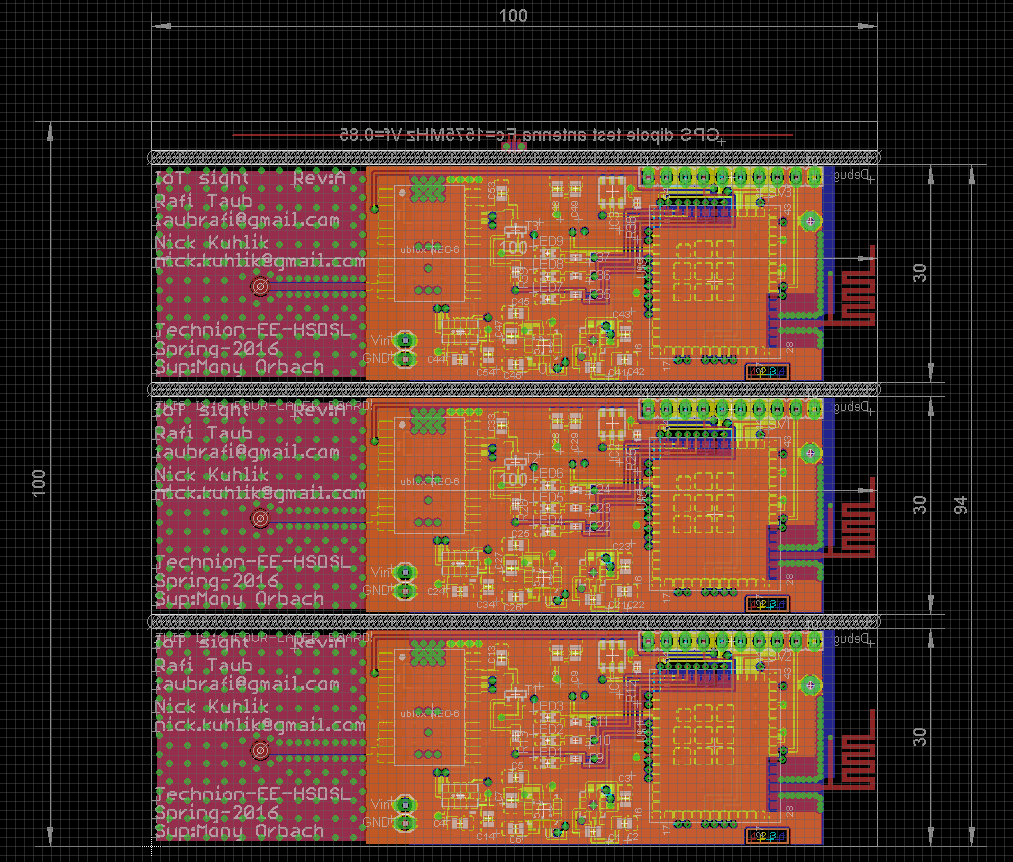
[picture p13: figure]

Figure 16: Full PCB for manufacturing

## 7.3 Appendix C: Full mechanical drawings

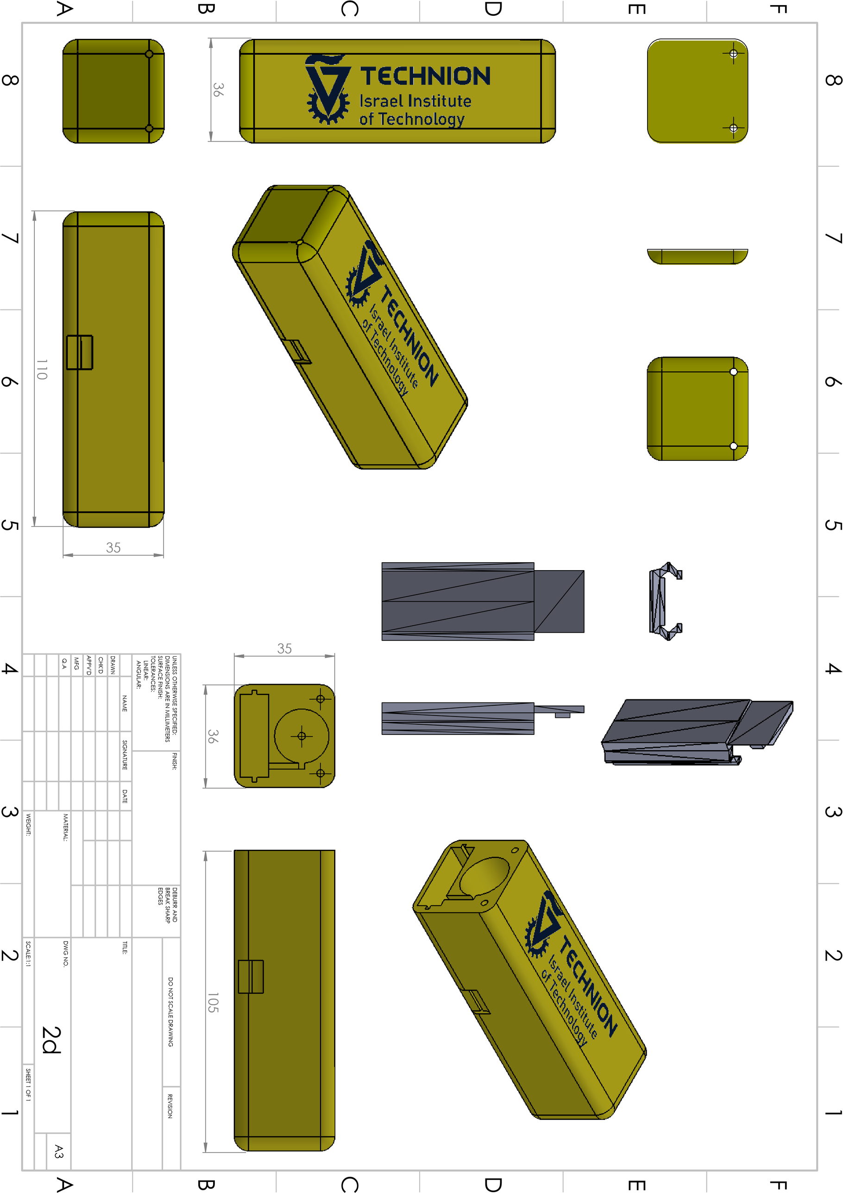
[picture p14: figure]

Figure 17: Mechanical diagrams

[^1] AN91445 from Cypress semiconductors

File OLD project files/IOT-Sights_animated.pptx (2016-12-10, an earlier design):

## IOT Sights

Students: Rafi Taub (taubrafi@gmail.com)
Nick Kuhlik (nick.kuhlik@gmail.com)
Supervisor: Moni Orbach
Semester: Spring 2016

## Introduction

- The modern assault rifle sights are an optical device that is lacking in features.
- The relay of tactical information in the field, back to the high command is mostly done by speech over the radio.
- By integrating smart IOT devices in the gear of the modern infantry, we can transmit back vital data that can help decision making.

## Project Goals

- Create a device that transmits GPS and position in space, to a server to intersect the data from several devices and show the result.
  - Learn how to develop code for microcontrollers.
  - Produce a PCB.
  - Create a website for visualization and data parsing.

## Solution Requirements

An embedded device that will be mounted on a Blue force rifle. Sending tactical information such as position and location via the internet for the commander to make decisions based on deduced position of Red force.

## Diagram Visualization

- In this diagram:
We can see the blue
Force location and the
Direction of their sights
When the trigger was
Pulled.
- We could deduce
The positions of the red
Force.

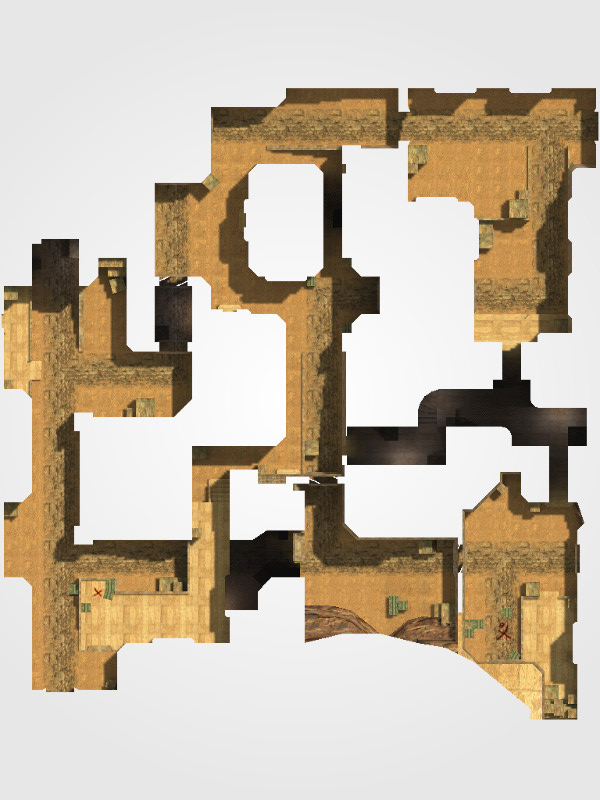
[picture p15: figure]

soldier position
Red force possible position
Line of sight at trigger pull

## Animated diagram

soldier position
Red force possible position
Line of sight at trigger pull

## Block Diagram: Overview

Data creation
Collection and analysis
Decision making

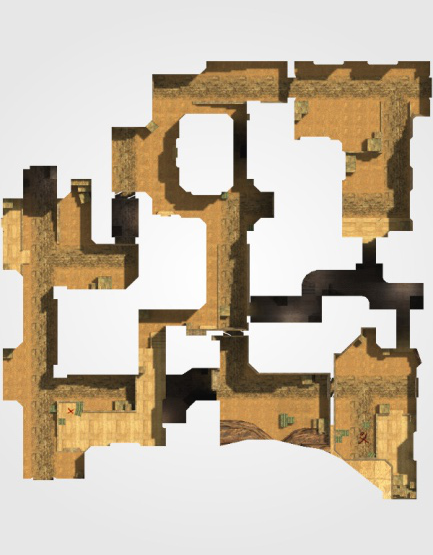
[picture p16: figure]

Algorithm on the AWS cloud

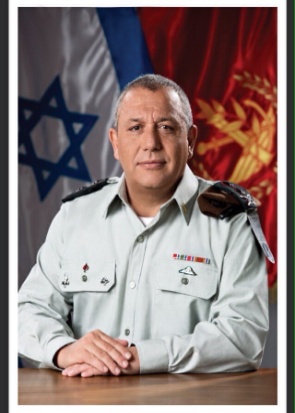
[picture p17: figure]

GPS and MEMS data from each

HMI

## Block Diagram: Embedded Device

microcontroller
Internet access
MEMS – position in space
GPS- Location in space
Trigger Pull detector
storage

## Project Gantt – until mid semester

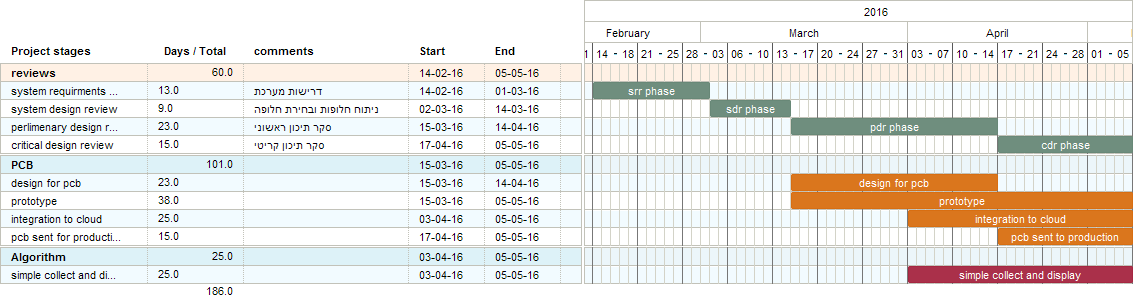
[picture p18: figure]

- In the SRR phase we will collect the requirements for the IOT sights, deciding the crucial parts and the “nice to have” ones.
- In the SDR phase we will propose different solutions that satisfy the requirements for the project and choose the best solution based on the weights given to each requirement
- In the PDR phase we will create the designs that will be used for manufacturing after the CDR and base our model from lessons learned from making a first iteration of breadboard prototype
- In the CDR phase we connect the singular system prototype to the cloud to deliver the full functionality.
- The conclusion of all of those stages will bring us to the midterm presentation .

## PDR readiness

- According to the Gantt:
  - The Prototype is on schedule.
  - The cloud integration is ahead of schedule
  - The PCB production is 2 weeks behind schedule (didn’t include Passover into the calculations)

## The PCB

- The PCB is sent into manufacturing.
- 3 PCB’s will be created for testing and further work.
- Code is located at https://github.com/taubrafi/IoTsightembedded/tree/CC3200v2

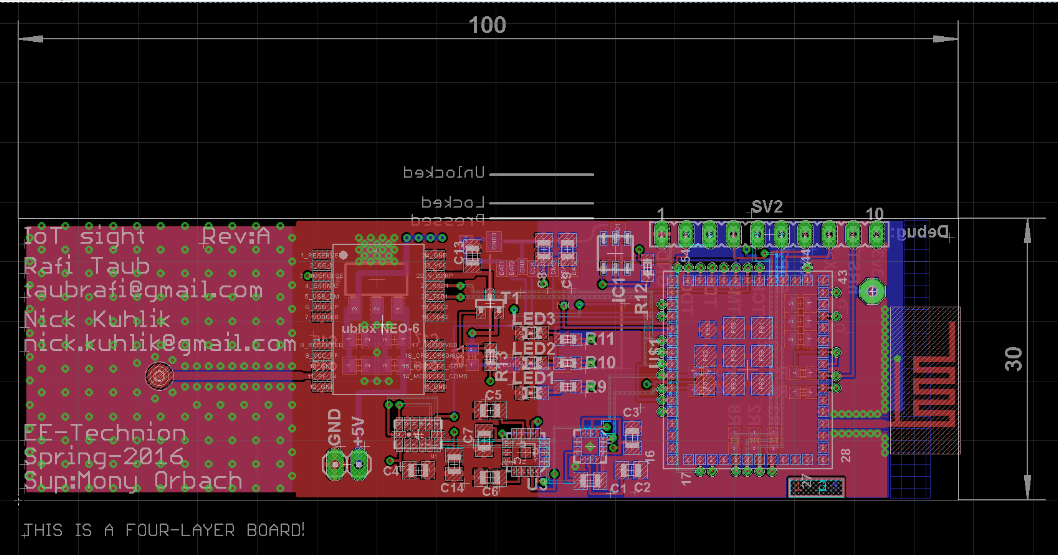
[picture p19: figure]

## The

- Site is located at http://52.50.107.126/ using AWS cloud.
- Code is located at https://github.com/sudo-Whateverman/IOTsights

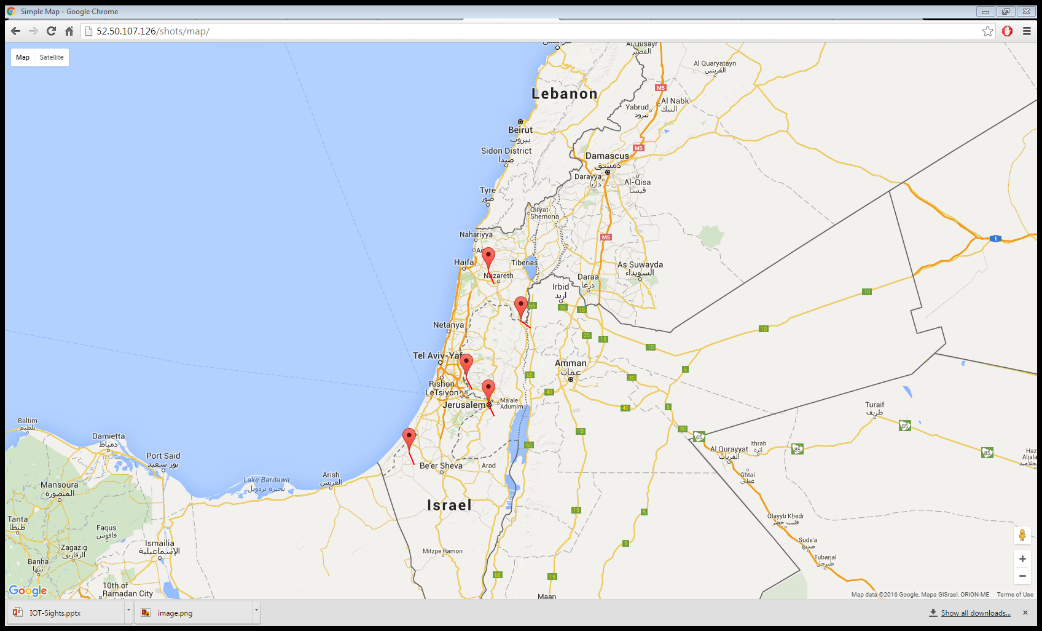
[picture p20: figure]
Simple Map - Google Chrome

## Future plans

- Integration Tests on PCB.
- Create a printed enclosure for the PCB and power supply.
- Test the device in “field conditions”.
- Add css to the website.
- Create version description document and signoff.

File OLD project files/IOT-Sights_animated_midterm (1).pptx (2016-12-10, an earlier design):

## IOT (Paintball) Sight

Students: Rafi Taub (taubrafi@gmail.com)
Nick Kuhlik (nick.kuhlik@gmail.com)
Supervisor: Moni Orbach
LAB: HSDLS EE Technion
Semester: Spring 2016-5776

## Introduction

- The modern assault rifle sights is an optical device that is lacking in features.
- The relay of tactical information in the field, back to the high command is mostly done by speech over the radio.
- By integrating smart IOT devices in the gear of the modern infantry, we can transmit back vital data that can help decision making.

Problem Statement

## Block Diagram: Overview

Data creation
Collection and analysis
Decision making


Algorithm on the AWS cloud


GPS and MEMS data from each

HMI

## The cloud

- Site is located at http://52.50.107.126/ using AWS cloud.
- Code is located at https://github.com/sudo-Whateverman/IOTsights

Simple Map - Google Chrome

## The cloud architecture

- Server provider
- AWS cloud
- Server OS
- Ubuntu
- HTTP server
- Apache
- Web application
- Written in python and js using Django and google maps api

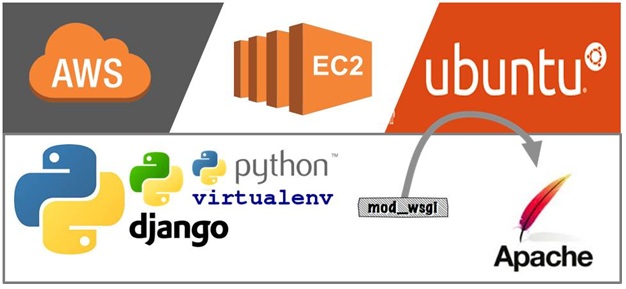
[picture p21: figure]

## Implementation rational

FOSS – free open source software
Scalable solution – the same image can be implemented many times behind an elastic load balancer
Easy to develop – python is just easy

## Block Diagram: Embedded Device

CC3200 MCU
Internet access: Wi-Fi
MEMS: orientation in space
GPS: location in space
Fired shot detection
SD storage
Barometer: relative altitude

## Embedded software: key components

- Shot fired detection
- Read & process sensor data: GPS, accelerometer, magnetometer and barometer
- Calculate orientation angles (roll, pitch, heading)
- Unique hardware ID
- Wi-Fi and connection to server
- SD card for record keeping
- Hibernation & wakeup (power saving)

## Orientation mathematics

- φ=atan2(G_(py) , G_(pz) )
- θ=atan2(−G_(px) , G_(py) sinφ+G_(pz) cosφ)
- ψ=atan2((B_(pz) −V_z )sinφ−(B_(py) −V_y )cosφ,(B_(px) −V_x )cosθ+(B_(py) −V_y )sinθsinφ+(B_(pz) −V_z )sinθcosφ)

## Embedded software: what remains

- Read & process GPS data *in progress*
- Read & process barometer data *waiting for parts*
- Unique hardware ID *waiting for parts*
- Shot fired detection *in progress*
- Hibernation/wakeup/power *up next*
- Gyroscope sensor fusion *evaluating*

## PCB design


## Current PCB

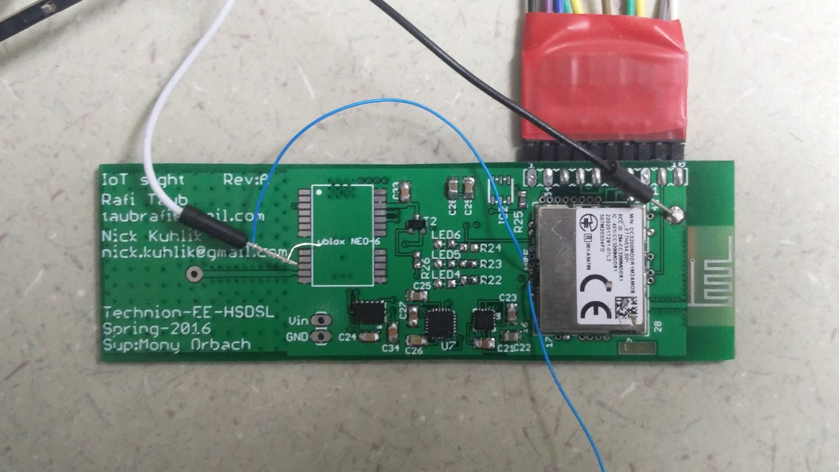
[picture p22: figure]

## Debugging

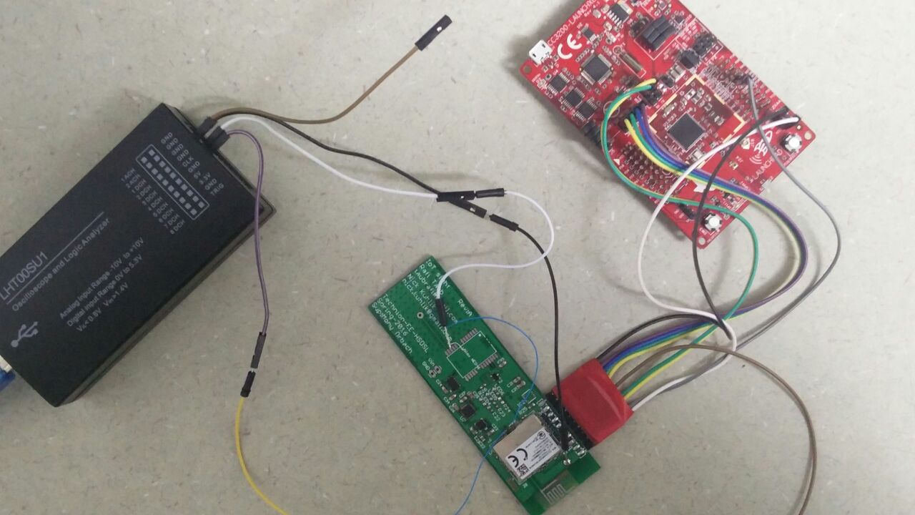
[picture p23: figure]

## Preliminary enclosure design

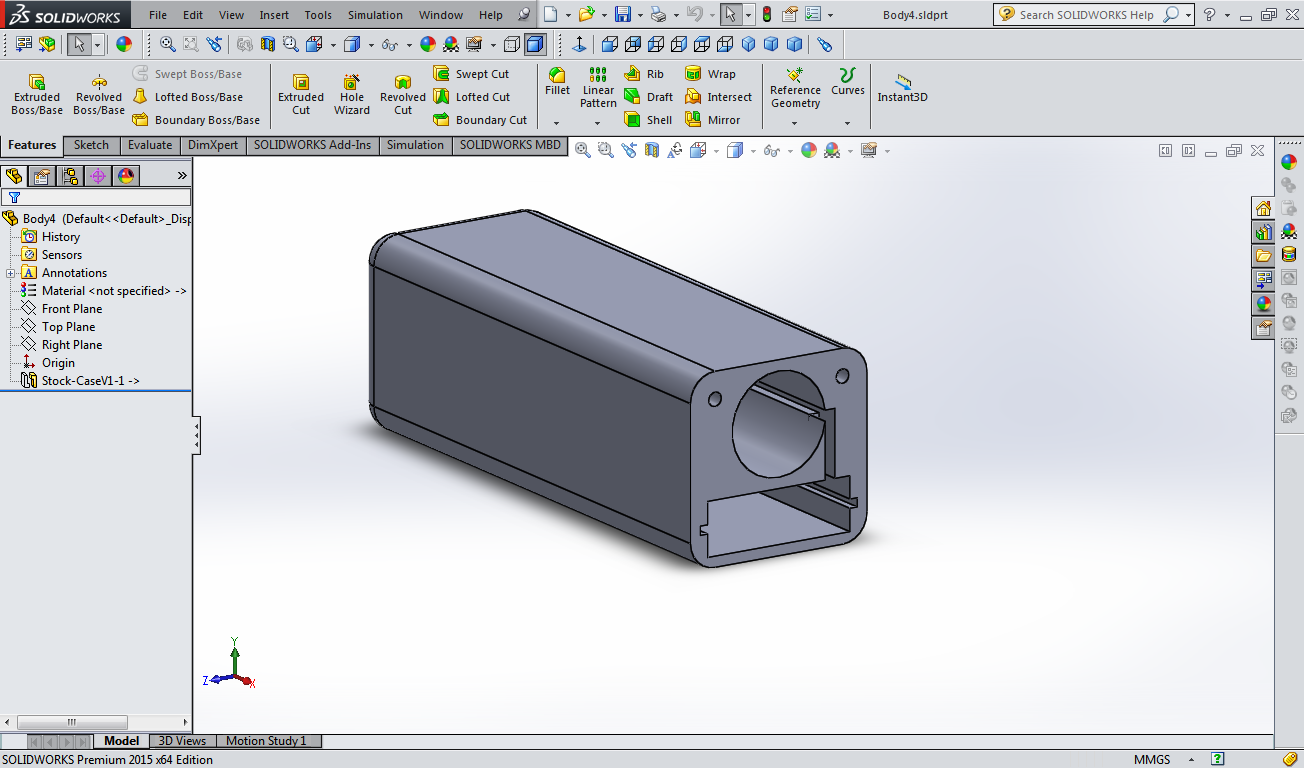
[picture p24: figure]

## Preliminary enclosure


## Power consumption

- Intended battery: 2200mAh 3.7v lithium, size 18650
- Power consumption:
  - GPS: active 22mA, idle:22μA
  - Accelerometer: active 30μA, ~~idle 0.1~~~~μ~~~~A~~
  - Magnetometer: active 100μA, idle 2μA
  - Microcontroller: active ~20mA, transmitting 200mA, low power mode 0.9mA, hibernation 7 μA

## Battery life

- Minimalist: (not the best)
  - No GPS until needed, requires 30 seconds to lock (cold start)
  - Avg. current ~1mA, battery life of 96 days.
- Theoretical battery life: (best case)
  - Never has to broadcast message
  - GPS active for 5 one second intervals every minute (hot start)
  - Accelerometer always active (independently detects shot fired)
  - Avg. current: ~4.3mA, battery life of 21 days!
- Worst case:
  - Shots fired one after the next (without better algorithm)
  - Avg. current ~54mA, battery life of 40hrs.

## Project Gantt – until mid semester


- In the SRR phase we will collect the requirements for the IOT sights, deciding the crucial parts and the “nice to have” ones.
- In the SDR phase we will propose different solutions that satisfy the requirements for the project and choose the best solution based on the weights given to each requirement
- In the PDR phase we will create the designs that will be used for manufacturing after the CDR and base our model from lessons learned from making a first iteration of breadboard prototype
- In the CDR phase we connect the singular system prototype to the cloud to deliver the full functionality.
- The conclusion of all of those stages will bring us to the midterm presentation .

## TRR readiness

- According to the Gantt:
  - The PCB is delivered but some parts still arrive.
  - Basic mechanics are complete, mounting on picatiny rail to be added.
  - The embedded software is almost done.
  - The cloud is stable and working, but lack css and looks bad. We need to see what algorithmics should be implemented there.

## What’s next?

- Finish assembling PCB (when parts arrive)
- Complete minor additions to embedded software
- Implement power saving and hibernation to lengthen battery life.
- Improve web interface (CSS)
- Field testing (firing range?) - set goals for testing and condition for success.
- Add documentation and sign off.

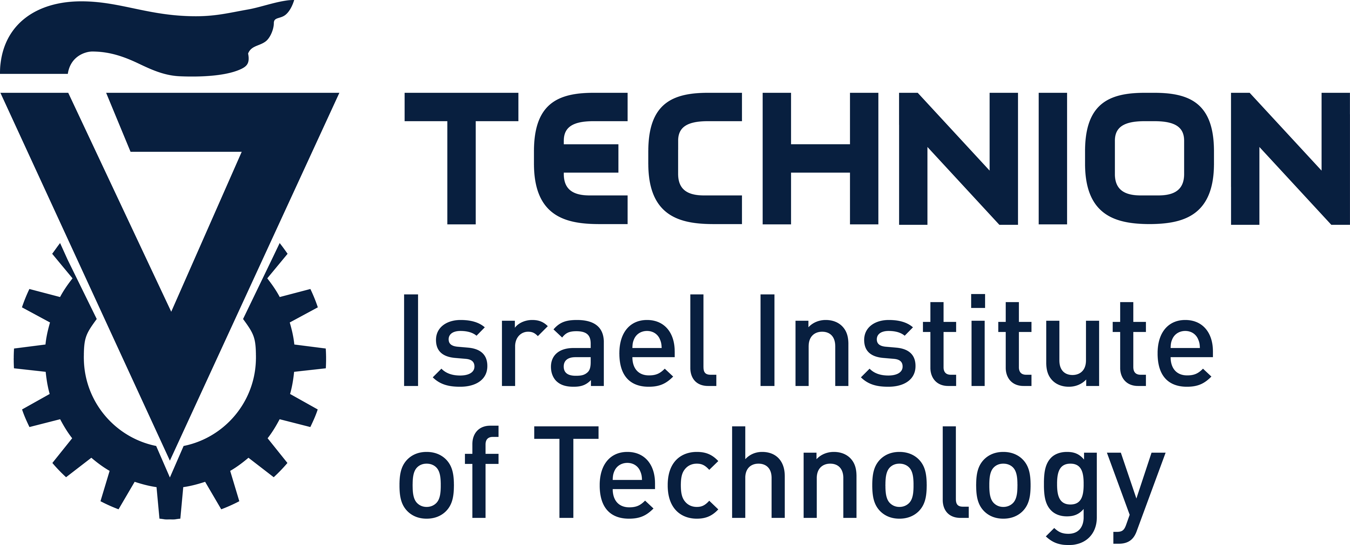
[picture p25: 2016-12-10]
Case/V2/Eng_Hor_Blue.jpg

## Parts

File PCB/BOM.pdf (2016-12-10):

Part | Value/part number | Qty | Package | Notes
ANT1, ANT2, ANT3 | ADA18182 | 3 GPS_Antenna patch
C2, C8, C10, C15, C17,C22, C28, C30, C35, C37,C42,
C1, C21,C41 | 0.22uF | 3 C-0805
C48, C50, C55, C57 | 4.7uf | 15 C-0805
C3, C4, C5, C7, C9, C11, C13, C14, C16, C18, C23, C24, C25, C27, C29, C31, C33, C34, C36, C38, C43, C44, C45, C47, C49, C51, C53, C54, C56, C58 C6, C26, C46 | 0.1uF 2.2nf | 30 C-0805 3 C-0805
C12, C32, C52 | 0.01uF | 3 C-0805
IC1, IC3 | DS2401P | 3 TSOC6
LED1, LED2, LED3, LED4, LED5, LED6, LED7, LED8, LED9 Generic 0805 LED | | 9 CHIPLED_0805
C19, C20, C39, C40, C59, C60 | 1uF | 6 C-0805
JP1, JP2, JP3 | 2908-05WB-MG | 3 MICRO-SD-SOCKET-SDIO
R1, R7, R14, R20, R27, R33 | 10k | 6 R-0603
R2, R4, R5, R12, R13, R15, R17, R18, R25, R26, R28, R30, R31, R38, R39 R3, R6, R8, R16, R19, R21, R29, R32, R34 | 2.7k 100k | 15 R-0603 9 R-0603
R9, R10, R11, R22, R23, R24, R35, R36, R37 | 470R | 9 R-0603
U$1, U$5, U$9 | CC3200MOD | 3 CC3200MOD
U$4, U$8, U$12 | MIC2920A-3.3WS-TR | 3 SOT223
U2, U6, U10 | HMC5883L | 3 16LPCC
U4, U8, U12 | MPL115A2 | 3 LGA8
T1, T2, T3 | PNP transistor | 3 SOT-23
U$2, U$6, U$10 | UBLOX_NEO-7P | 3 UBLOX_NEO-7P
U1, U5, U9 | ADXL345 | 3 LGA14
U3, U7, U11 | Do not populate

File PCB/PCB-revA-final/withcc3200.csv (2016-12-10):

Part | Value/part number | Qty | Package | Notes
ANT1, ANT2, ANT3 | ADA18182 | 1 | GPS_Antenna patch
C1, C21,C41 | 0.22uF | 1 | C-0805
C2, C8, C10, C15, C17,C22, C28, C30, C35, C37,C42, C48, C50, C55, C57 | 4.7uf | 5 | C-0805
C3, C4, C5, C7, C9, C11, C13, C14, C16, C18, C23, C24, C25, C27, C29, C31, C33, C34, C36, C38, C43, C44, C45, C47, C49, C51, C53, C54, C56, C58 | 0.1uF | 10 | C-0805
C6, C26, C46 | 2.2nf | 1 | C-0805
C12, C32, C52 | 0.01uF | 1 | C-0805
C19, C20, C39, C40, C59, C60 | 1uF | 2 | C-0805
IC1, IC3 | DS2401P | 1 | TSOC6 | DS2401P+
JP1, JP2, JP3 | 2908-05WB-MG | 1 | MICRO-SD-SOCKET-SDIO
LED1, LED2, LED3, LED4, LED5, LED6, LED7, LED8, LED9 | Generic 0805 LED | 3 | CHIPLED_0805
R1, R7, R14, R20, R27, R33 | 10k | 2 | R-0603
R2, R4, R5, R12, R13, R15, R17, R18, R25, R26, R28, R30, R31, R38, R39 | 2.7k | 5 | R-0603
R3, R6, R8, R16, R19, R21, R29, R32, R34 | 100k | 3 | R-0603
R9, R10, R11, R22, R23, R24, R35, R36, R37 | 470R | 3 | R-0603
T1, T2, T3 | PNP transistor | 1 | SOT-23 | May be called TP0610T
U$1, U$5, U$9 | CC3200MOD | 1 | CC3200MOD | Make sure suffix MOD !
U$2, U$6, U$10 | UBLOX_NEO-7P | 1 | UBLOX_NEO-7P
U$4, U$8, U$12 | MIC2920A-3.3WS-TR | 1 | SOT223
U1, U5, U9 | ADXL345 | 1 | LGA14
U2, U6, U10 | HMC5883L | 1 | 16LPCC | Make sure suffix L !
U3, U7, U11 | ITG-3200 | 1 | QFN-24
U4, U8, U12 | MPL115A2 | 1 | LGA8 | Make sure suffix A2 !

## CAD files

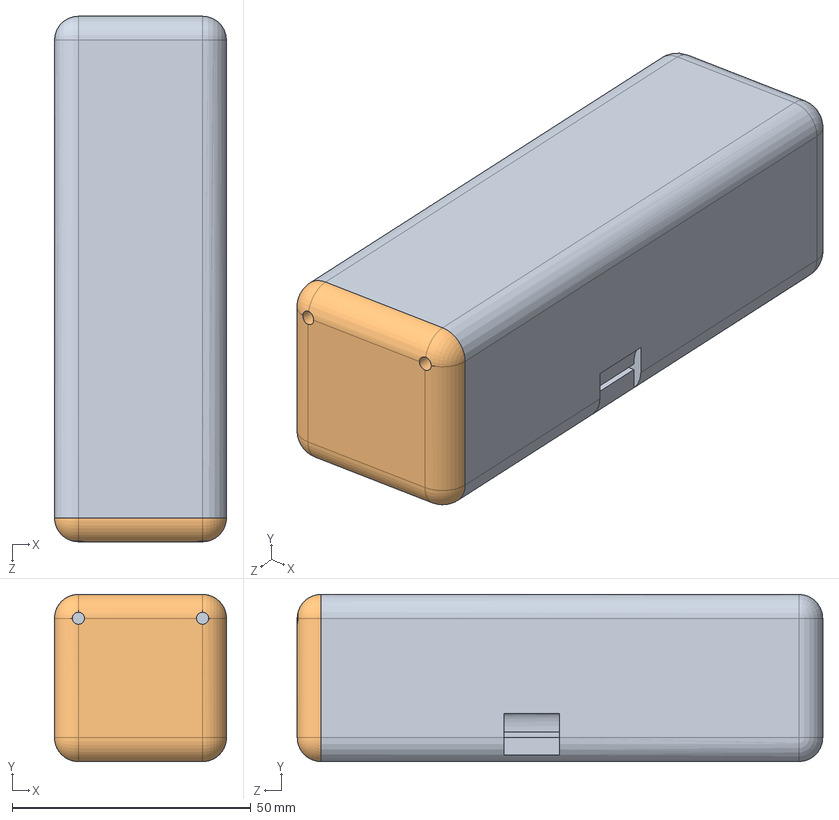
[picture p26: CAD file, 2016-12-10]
Case/V2/Assembly.SLDASM
36.0 x 35.0 x 110.0 mm

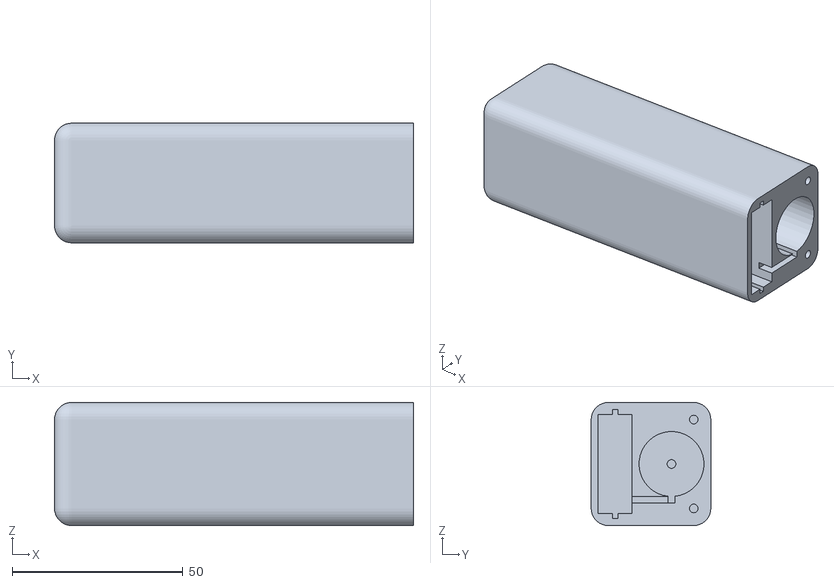
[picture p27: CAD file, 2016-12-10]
Case/Body4.STL
105.0 x 35.0 x 36.0

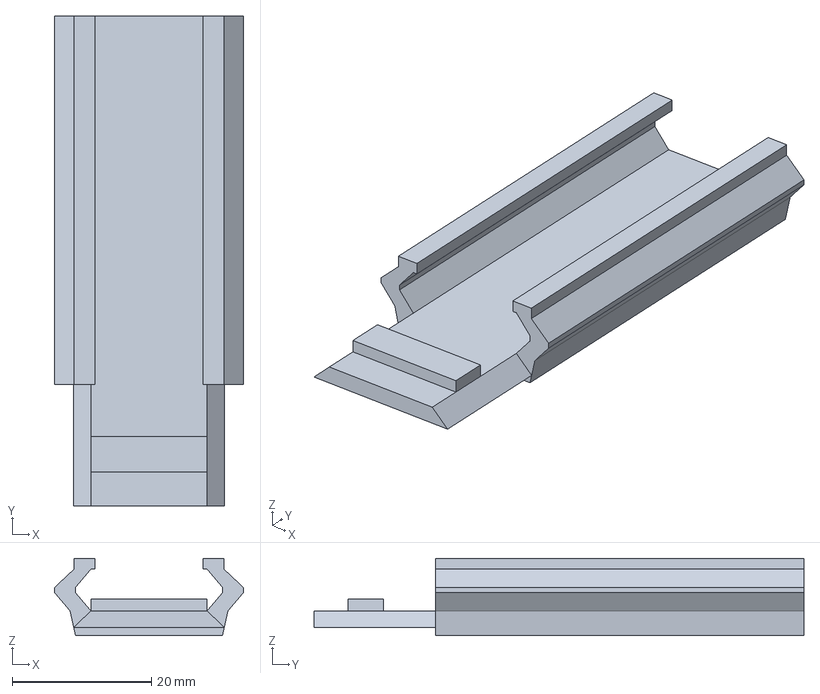
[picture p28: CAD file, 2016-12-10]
Case/Picatinny Rail (1).amf
27.2 x 70.4 x 11.1 mm

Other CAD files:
CC3200_workspace/adc/Release/optimizerAssistant/opt_for_speed__1/main.obj
CC3200_workspace/adc/Release/optimizerAssistant/opt_for_speed__3/main.obj
CC3200_workspace/adc/Release/optimizerAssistant/opt_for_speed__5/main.obj
CC3200_workspace/adc/Release/optimizerAssistant/opt_for_speed__0/main.obj
CC3200_workspace/adc/Release/optimizerAssistant/opt_for_speed__4/main.obj
CC3200_workspace/adc/Release/optimizerAssistant/opt_for_speed__2/main.obj
Case/V2/Body4.sldprt
CC3200_workspace/adc/Release/optimizerAssistant/opt_for_speed__0/pinmux.obj
CC3200_workspace/adc/Release/optimizerAssistant/opt_for_speed__1/startup_ccs.obj
CC3200_workspace/adc/Release/optimizerAssistant/opt_for_speed__2/startup_ccs.obj
CC3200_workspace/adc/Release/optimizerAssistant/opt_for_speed__3/startup_ccs.obj
CC3200_workspace/adc/Release/optimizerAssistant/opt_for_speed__4/uart_if.obj
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

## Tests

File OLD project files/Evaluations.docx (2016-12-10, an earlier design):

- GPS position, Orientation, Heading
  - Accuracy, repeatability
- Device performance
  - Battery Life
    - Worst case
    - Non-worst case
  - Wi-Fi antenna range
- Fire “Tap” detection
  - Reliability
  - Reaction time

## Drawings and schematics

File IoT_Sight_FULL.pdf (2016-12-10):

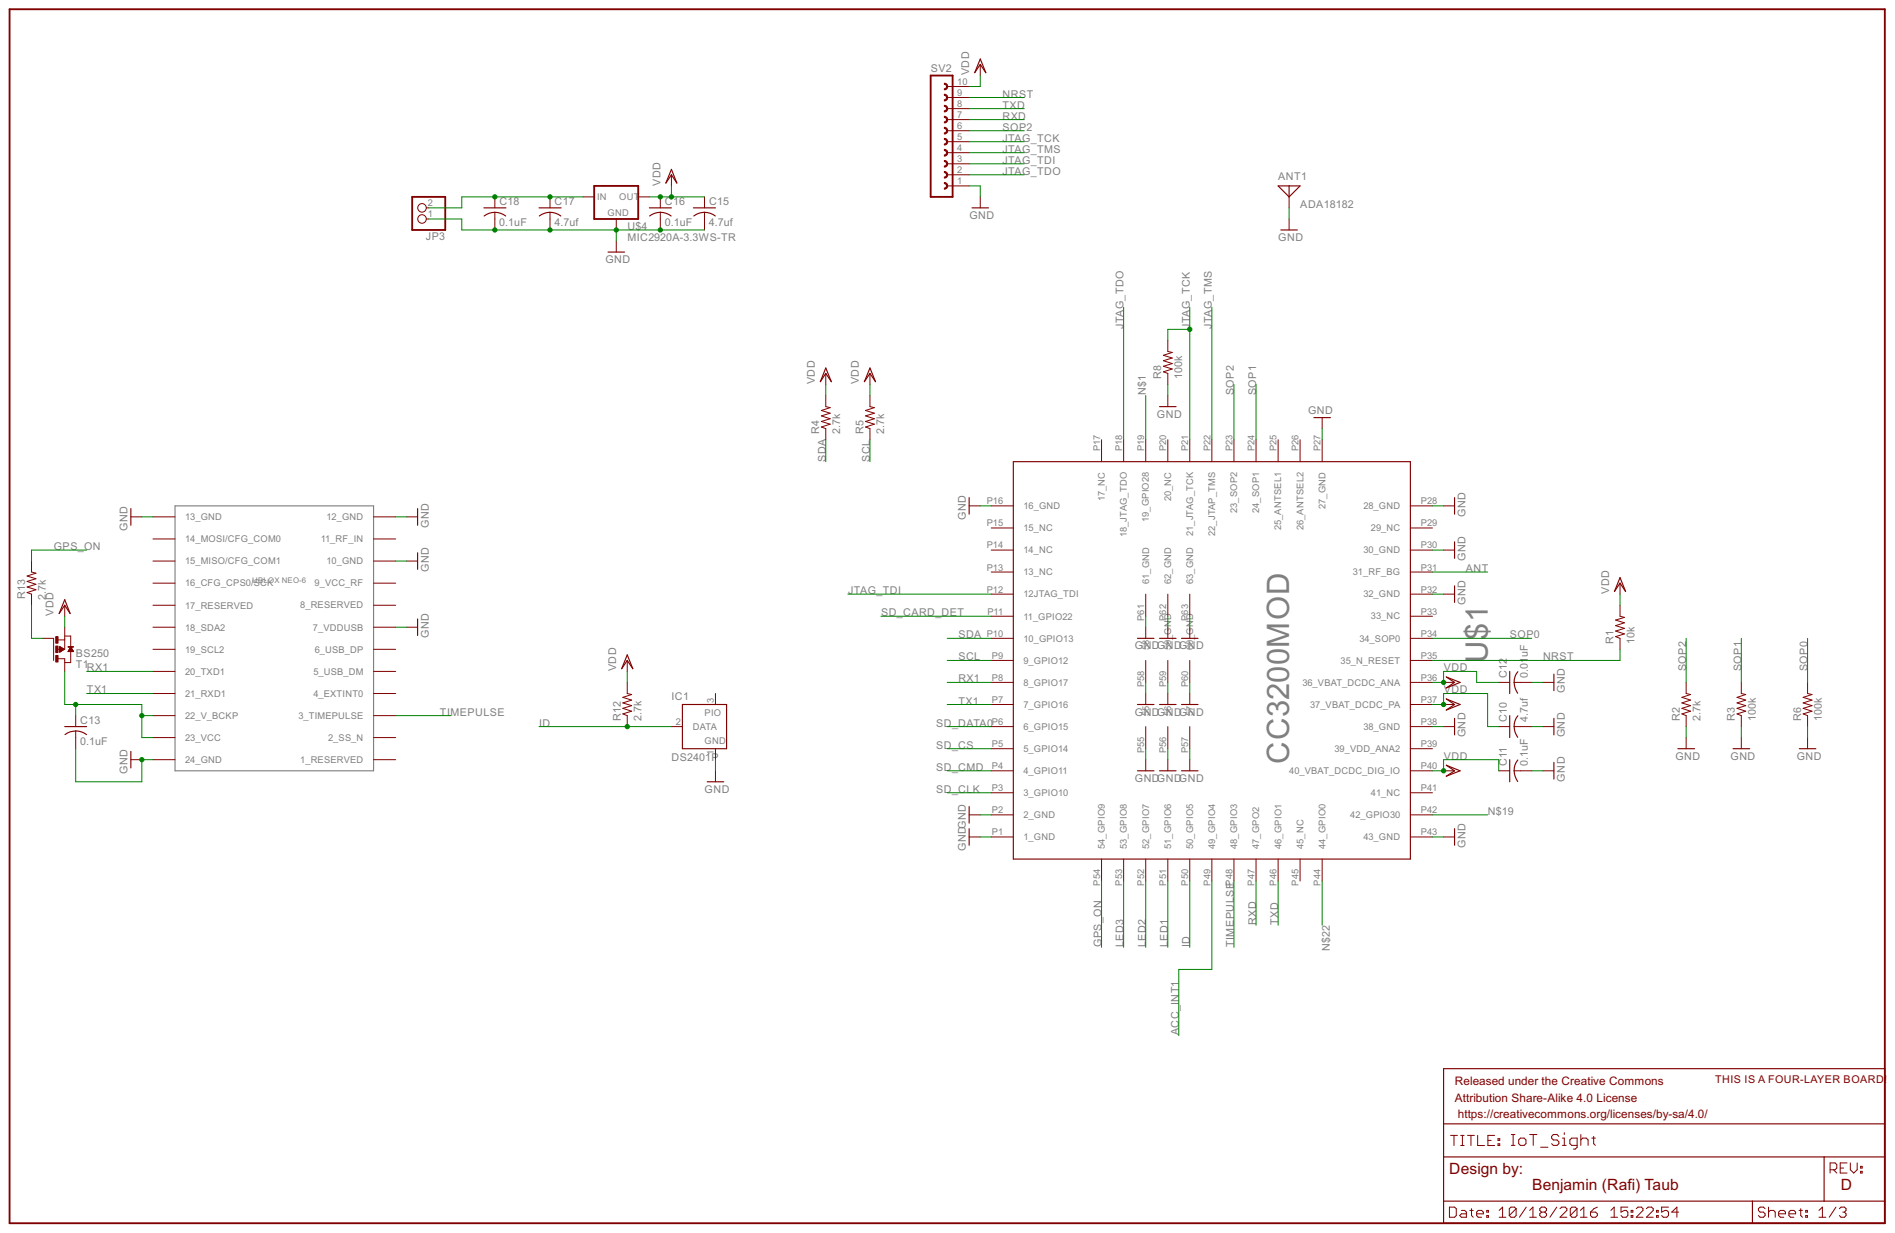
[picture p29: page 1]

https://creativecommons.org/licenses/by-sa/4.0/ Design by:

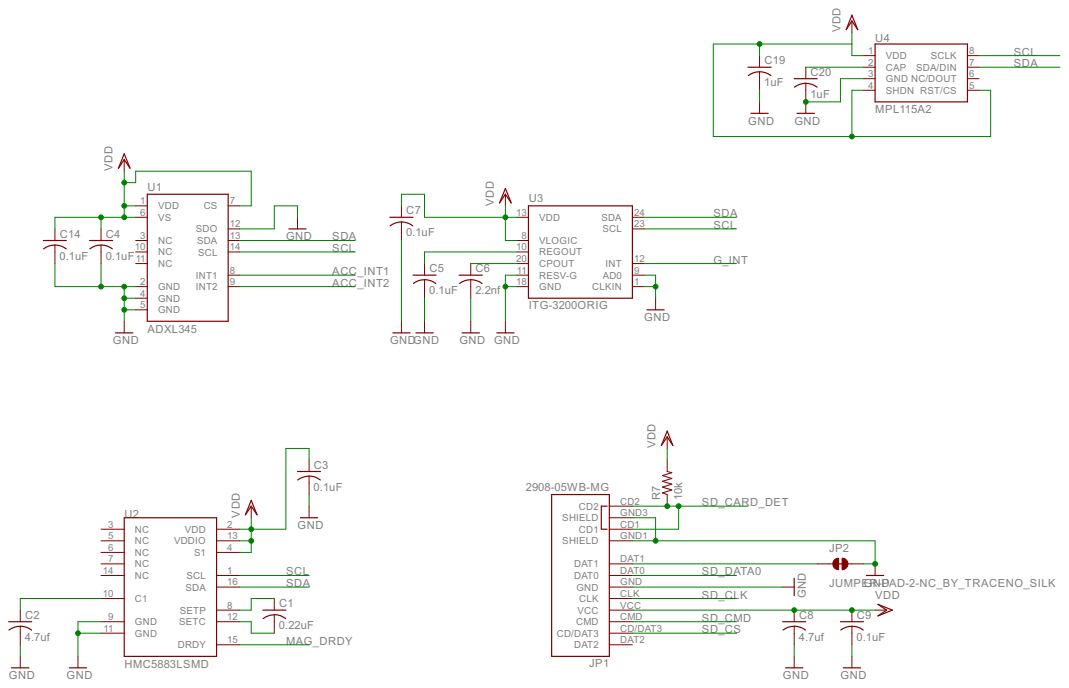
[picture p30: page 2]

Released under the Creative Commons Attribution Share-Alike 4.0 License

https://creativecommons.org/licenses/by-sa/4.0/ Design by:

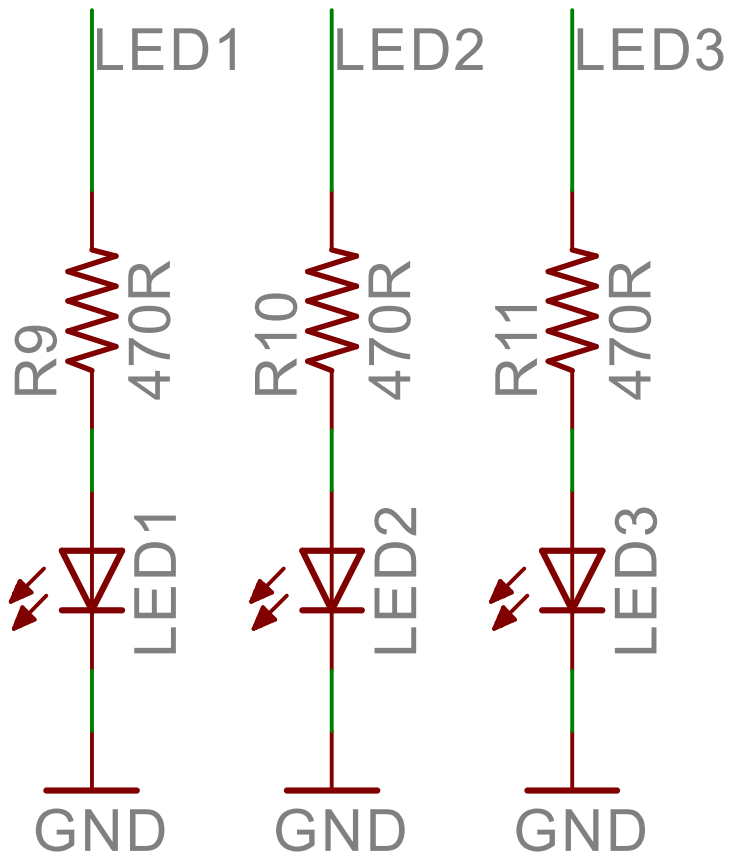
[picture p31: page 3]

470R 470R 470R GND GND GND LED1 LED2 LED3 R9 R10 R11 LED1 LED2 LED3 Benjamin (Rafi) Taub D Released under the Creative Commons Attribution Share-Alike 4.0 License https://creativecommons.org/licenses/by-sa/4.0/ Design by:

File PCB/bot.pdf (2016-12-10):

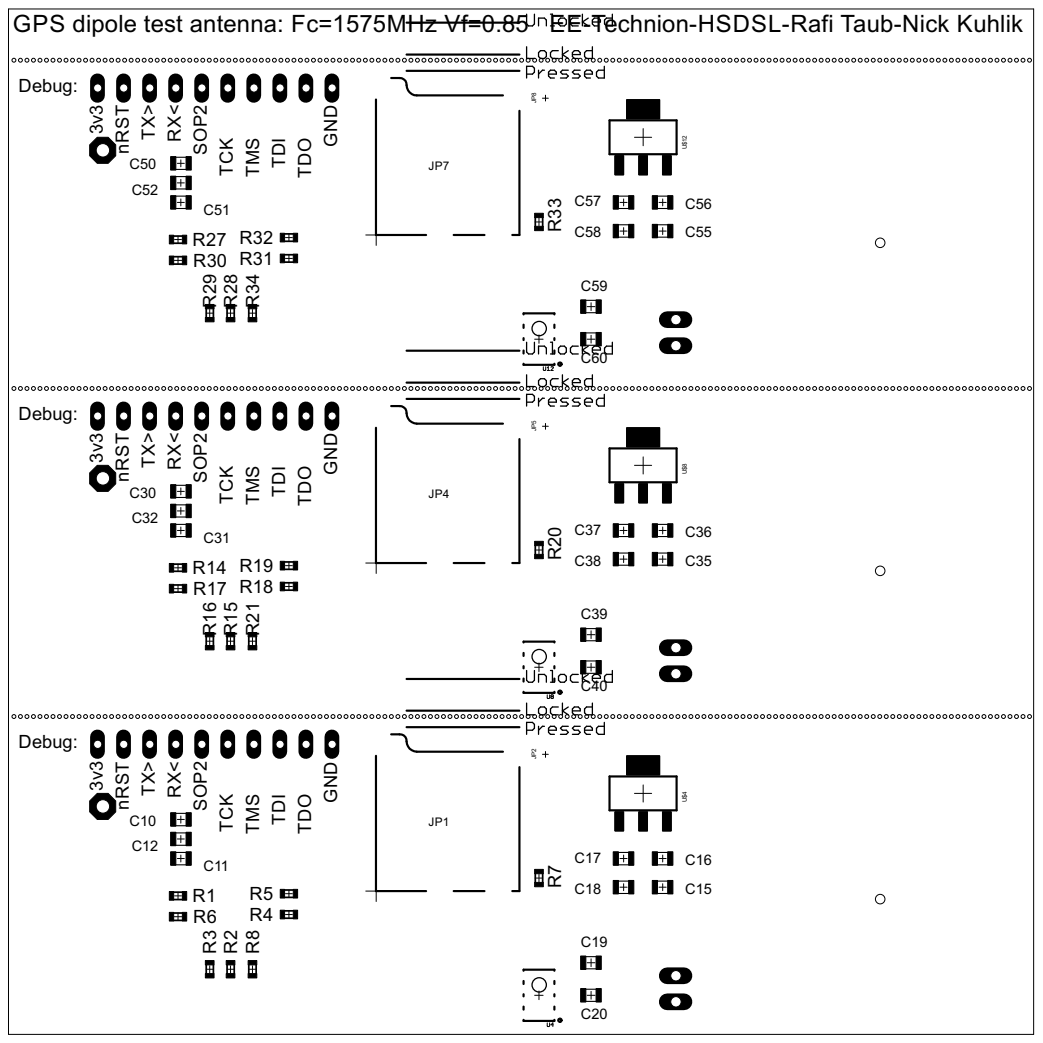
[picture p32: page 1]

3v3 GPS dipole test antenna: Fc=1575MHz Vf=0.85 EE-Technion-HSDSL-Rafi Taub-Nick Kuhlik

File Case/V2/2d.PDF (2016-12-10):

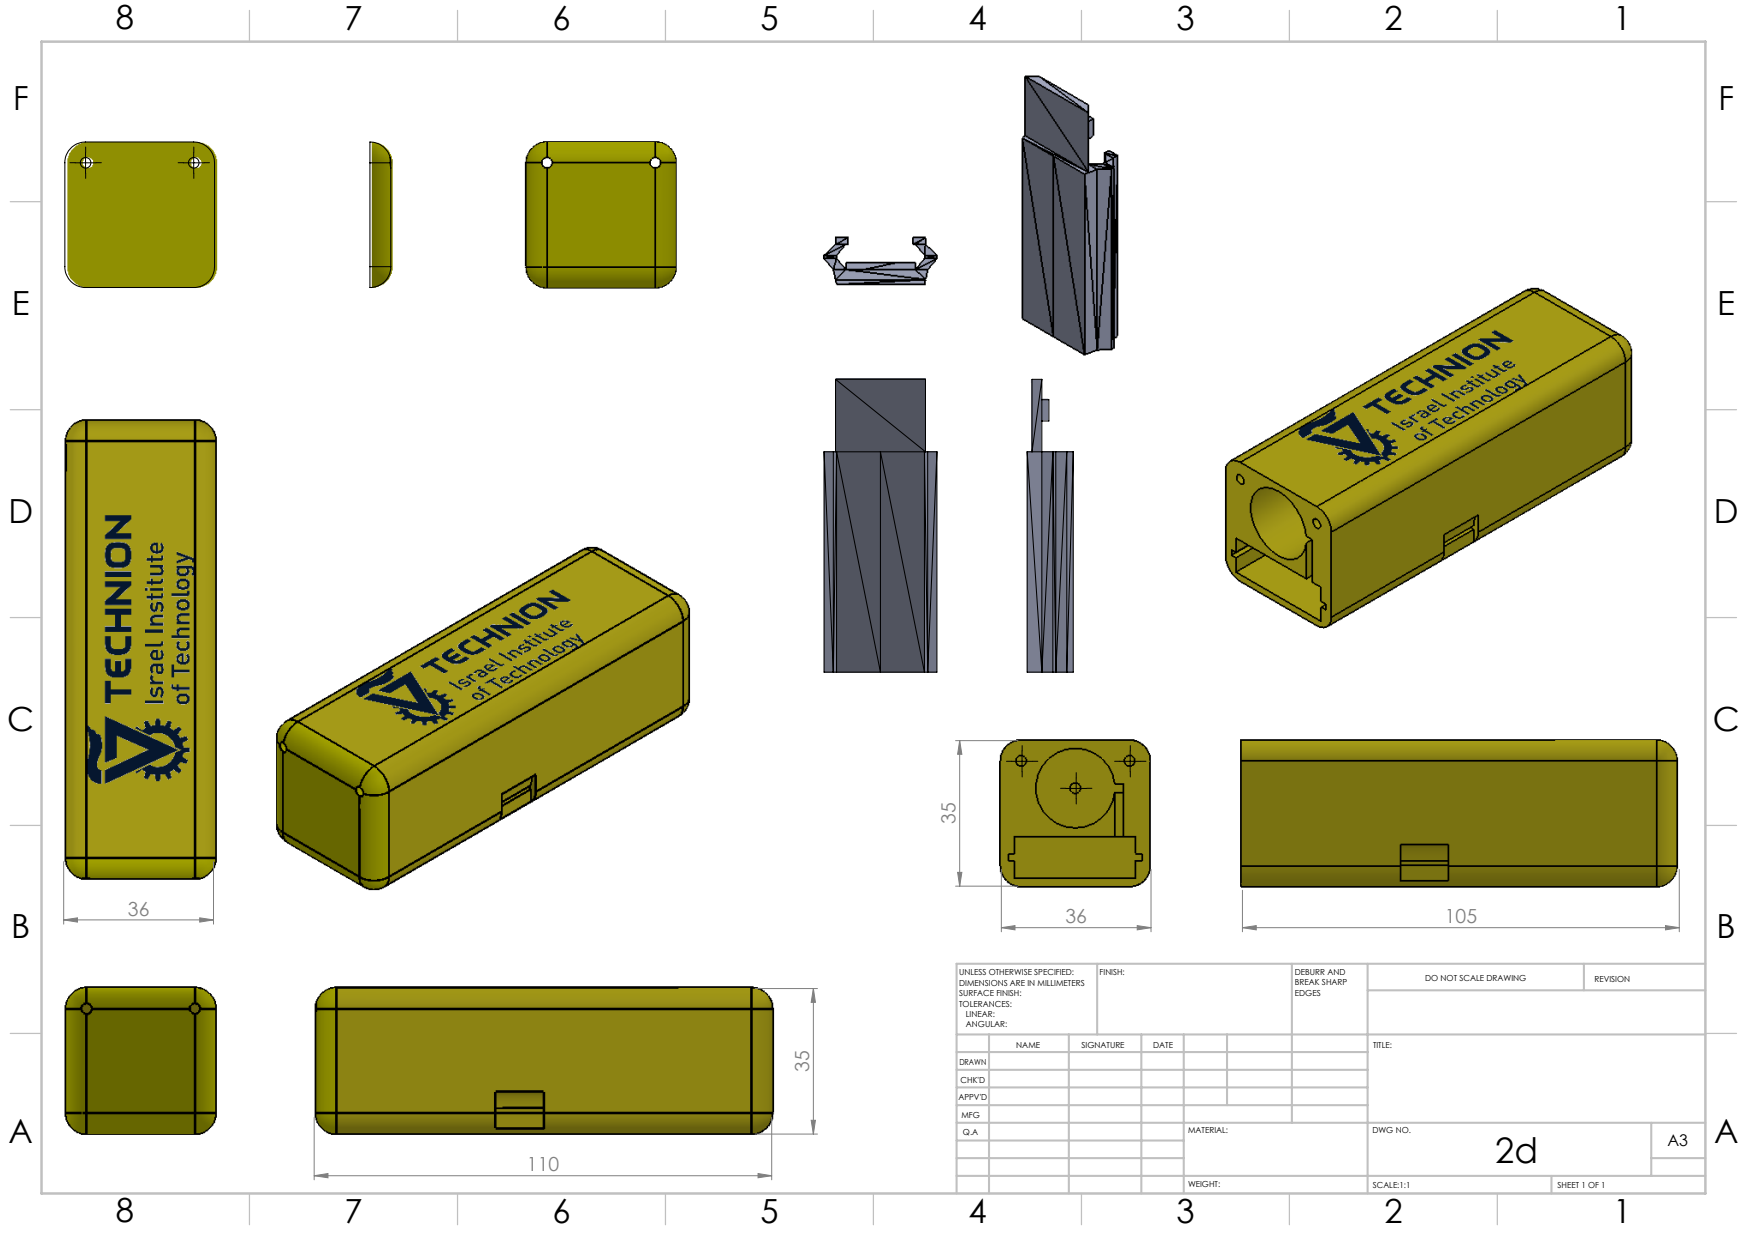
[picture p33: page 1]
FINISH:; DEBURR AND; BREAK SHARP; DO NOT SCALE DRAWING; REVISION; SCALE:1:1; SHEET 1 OF 1

UNLESS OTHERWISE SPECIFIED:
DIMENSIONS ARE IN MILLIMETERS
SURFACE FINISH:
TOLERANCES:
LINEAR:
ANGULAR:

NAME | SIGNATURE | DATE | | | | TITLE:

DRAWN
CHK'D
APPV'D
MFG
Q.A | | | | MATERIAL: | DWG NO. 2d | A3

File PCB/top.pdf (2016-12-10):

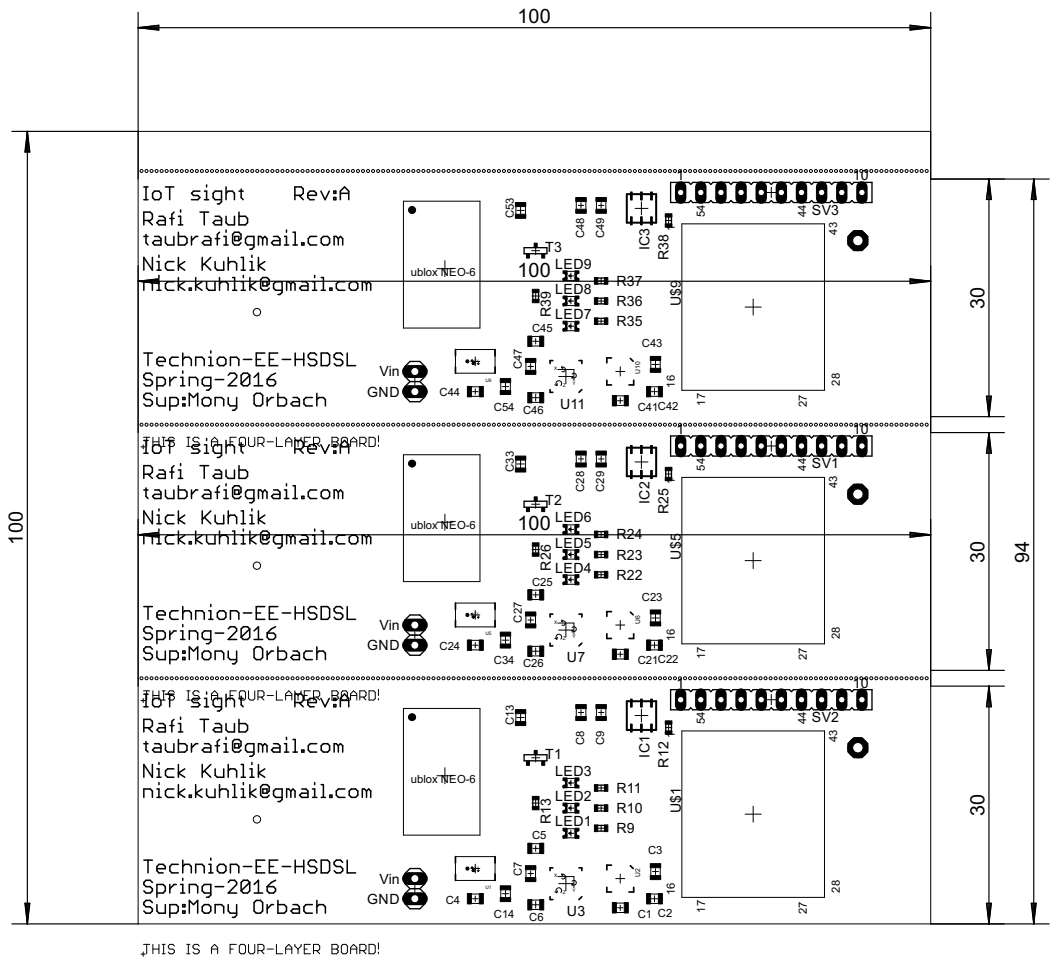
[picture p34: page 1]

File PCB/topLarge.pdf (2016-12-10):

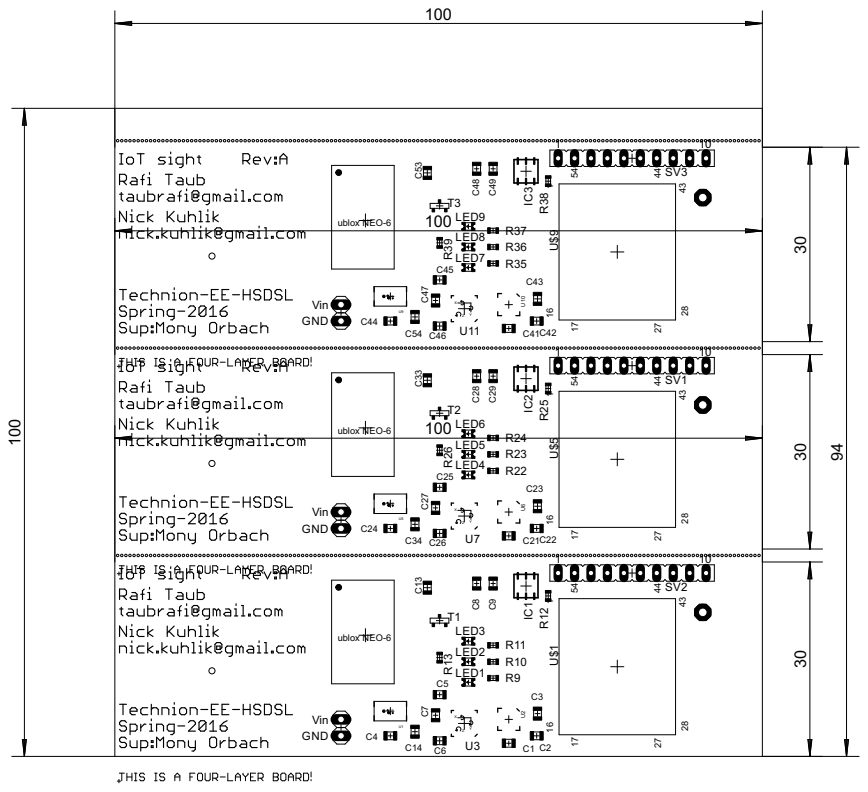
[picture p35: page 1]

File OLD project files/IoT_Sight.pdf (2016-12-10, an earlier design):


https://creativecommons.org/licenses/by-sa/4.0/ Design by:

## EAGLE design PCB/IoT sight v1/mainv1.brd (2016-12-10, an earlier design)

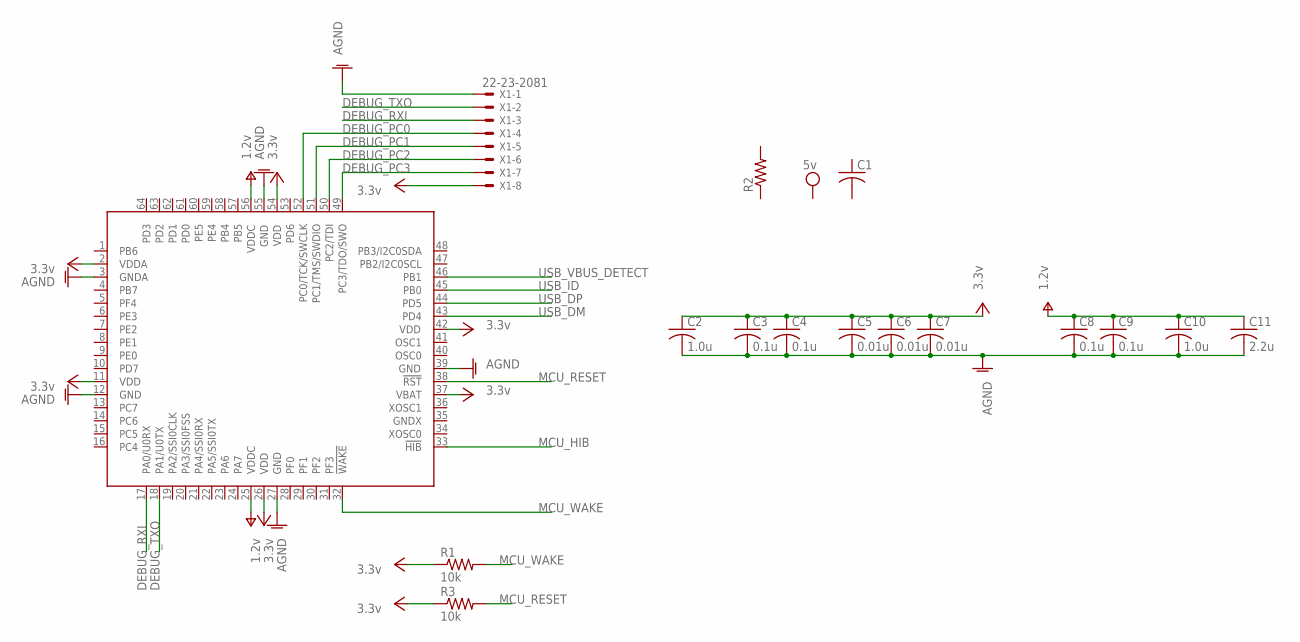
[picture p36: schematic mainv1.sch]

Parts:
C1: C-USC0805K; C0805K
C2, C10: 1.0u; C0805K
C3, C4, C8, C9: 0.1u; C0805K
C5, C6, C7: 0.01u; C0805K
C11: 2.2u; C0805K
IC1: TM4C123GH6PMI; PM_S-PQFP-G64
R1, R3: 10k; R0805
R2: R-US_R0805; R0805
X1: 22-23-2081

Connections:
AGND: C2.2, C3.2, C4.2, C5.2, C6.2, C7.2, C8.2, C9.2, C10.2, C11.2, IC1.3 (GNDA), IC1.12 (GND), IC1.27 (GND), IC1.39 (GND), IC1.55 (GND), X1.1
DEBUG_PC0: IC1.52 (PC0/TCK/SWCLK), X1.4
DEBUG_PC1: IC1.51 (PC1/TMS/SWDIO), X1.5
DEBUG_PC2: IC1.50 (PC2/TDI), X1.6
DEBUG_PC3: IC1.49 (PC3/TDO/SWO), X1.7
DEBUG_RXI: IC1.17 (PA0/U0RX), X1.3
DEBUG_TXO: IC1.18 (PA1/U0TX), X1.2
MCU_HIB: IC1.33 (!HIB)
MCU_RESET: IC1.38 (!RST), R3.2
MCU_WAKE: IC1.32 (!WAKE), R1.2
USB_DM: IC1.43 (PD4)
USB_DP: IC1.44 (PD5)
USB_ID: IC1.45 (PB0)
USB_VBUS_DETECT: IC1.46 (PB1)
V+: C8.1, C9.1, C10.1, C11.1, IC1.25 (VDDC), IC1.56 (VDDC)
VCC: C2.1, C3.1, C4.1, C5.1, C6.1, C7.1, IC1.2 (VDDA), IC1.11 (VDD), IC1.26 (VDD), IC1.37 (VBAT), IC1.42 (VDD), IC1.54 (VDD), R1.1, R3.1, X1.8

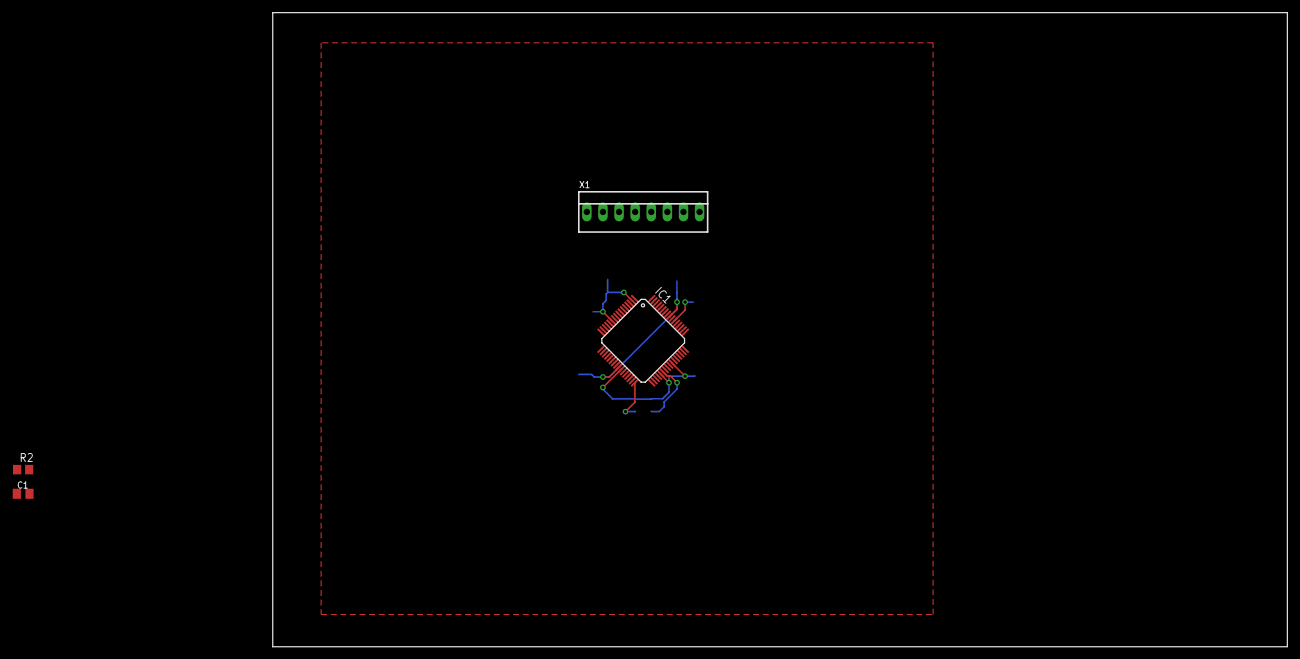
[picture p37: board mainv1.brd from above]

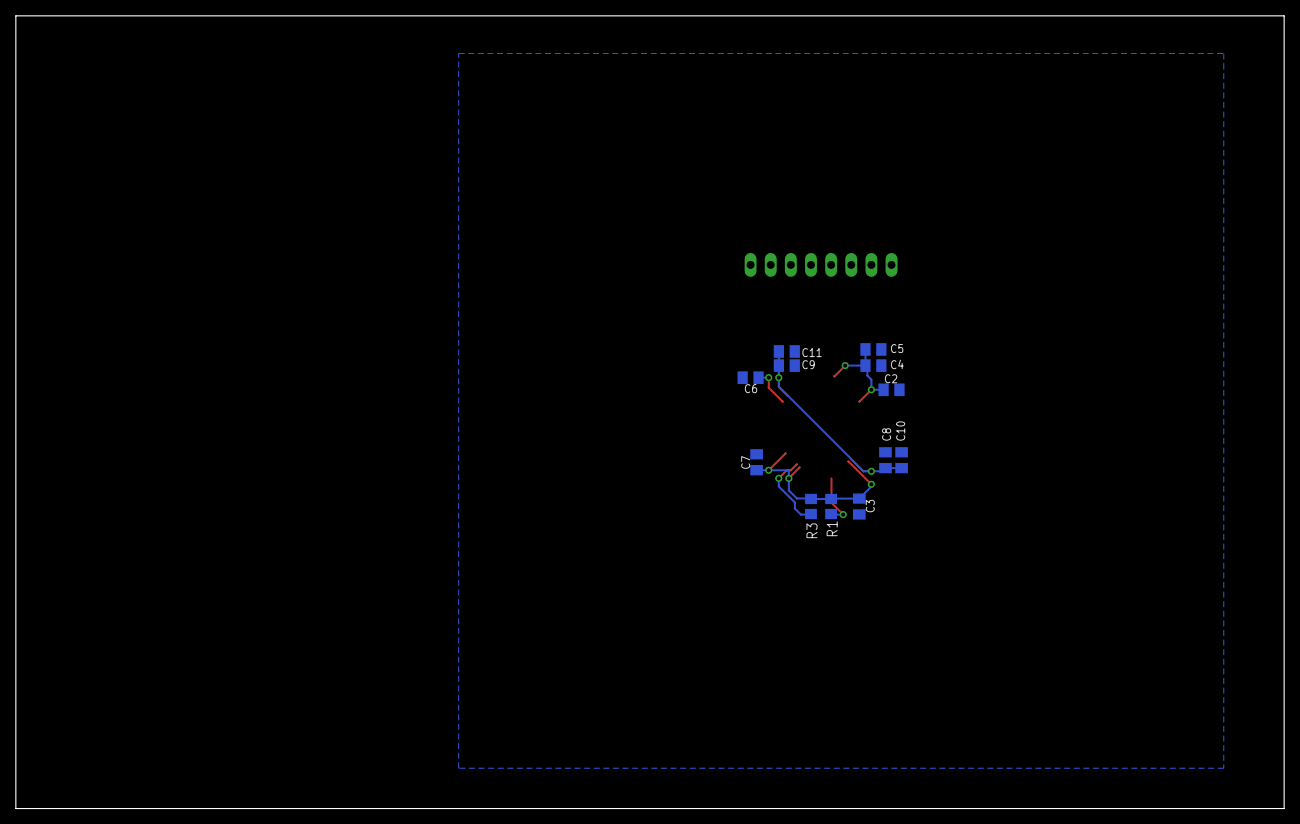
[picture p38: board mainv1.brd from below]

Board: 2 copper layers, 160.0 x 100.0 mm, 16 parts (12 on the bottom side), 11 nets.

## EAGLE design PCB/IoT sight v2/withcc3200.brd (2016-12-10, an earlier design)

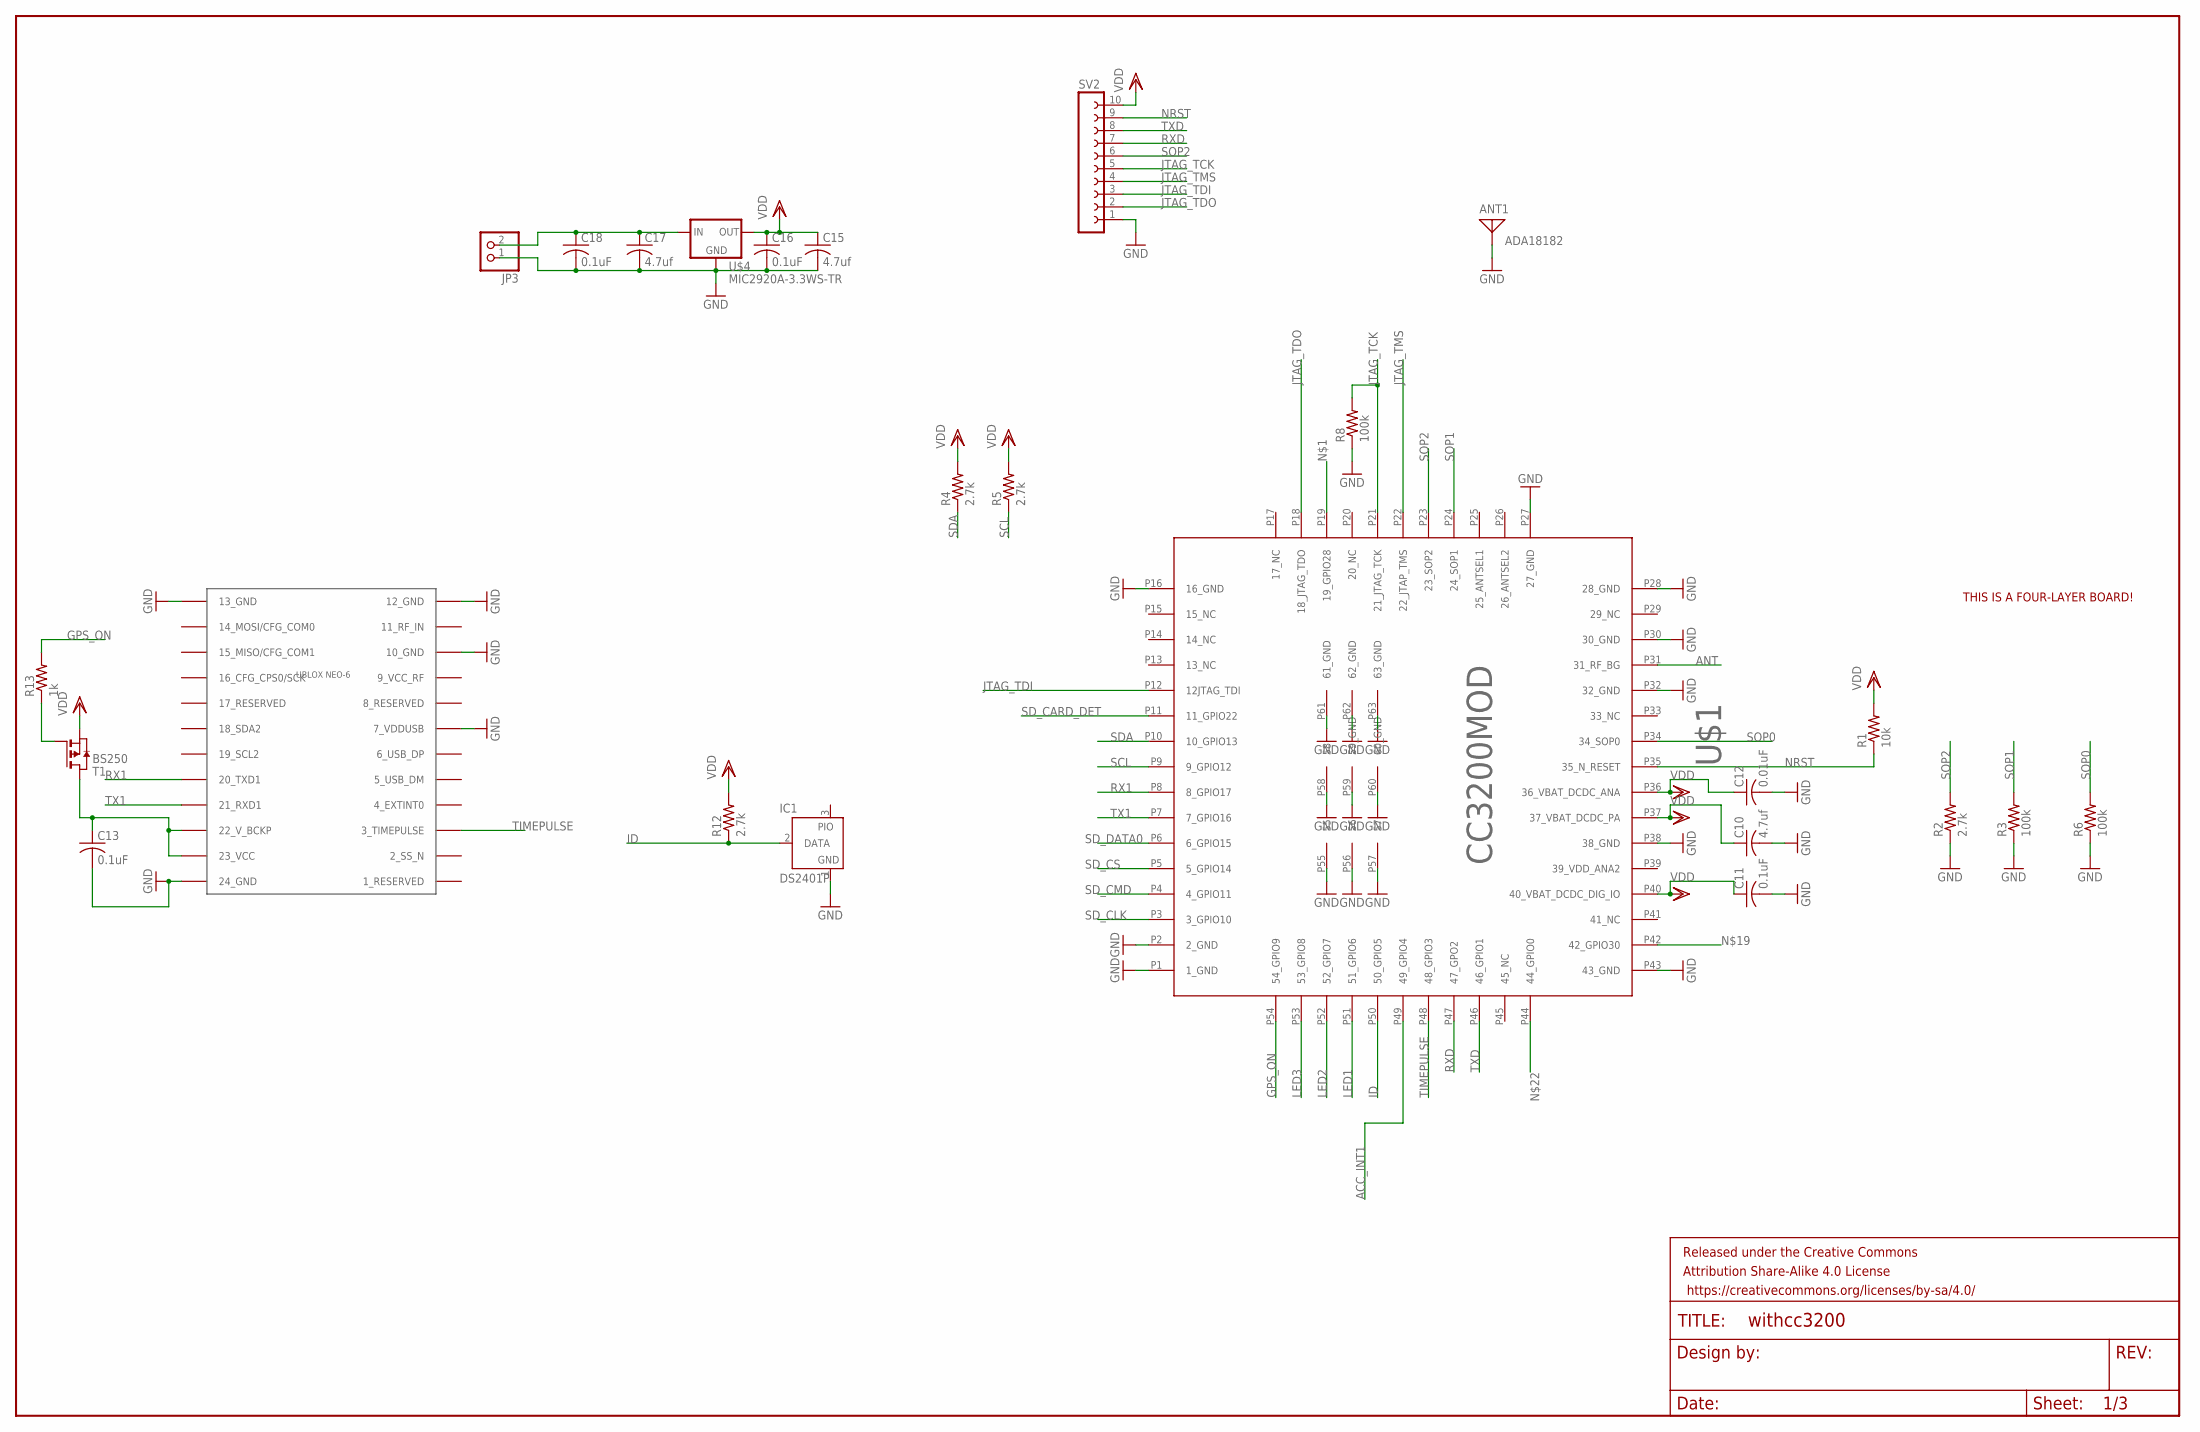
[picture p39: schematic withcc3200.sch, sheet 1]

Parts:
ANT1: ADA18182; PAD-01
C10, C15, C17: 4.7uf; C0805K
C11, C13, C16, C18: 0.1uF; C0805K
C12: 0.01uF; C0805K
FRAME1: FRAME-LEDGER; CREATIVE_COMMONS
IC1: DS2401P; TSOC6
JP3: PINHD-1X2; 1X02
R1: 10k; R0603
R2, R4, R5, R12: 2.7k; R0603
R3, R6, R8: 100k; R0603
R13: 1k; R0603
SV2: FE10-1; FE10
T1: BS250; SOT-23
U$1: CC3200MOD
U$2: UBLOX_NEO-7; UBLOX_NEO-6P
U$3: FOUR_LAYER_WARNING
U$4: MIC2920A-3.3WS-TR; SOT223

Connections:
ACC_INT1: U$1.P49 (49_GPIO4); also elsewhere on the board
ANT: U$1.P31 (31_RF_BG)
GND: ANT1.1, C10.2, C11.2, C12.2, C13.2, C15.2, C16.2, C17.2, C18.2, IC1.1 (GND), JP3.1, R2.1, R3.1, R6.1, R8.1, SV2.1, U$1.P1 (1_GND), U$1.P2 (2_GND), U$1.P16 (16_GND), U$1.P27 (27_GND), U$1.P28 (28_GND), U$1.P30 (30_GND), U$1.P32 (32_GND), U$1.P38 (38_GND), U$1.P43 (43_GND), U$1.P55 (55), U$1.P56 (56), U$1.P57 (57), U$1.P58 (58), U$1.P59 (59_GND), U$1.P60 (60_GND), U$1.P61 (61_GND), U$1.P62 (62_GND), U$1.P63 (63_GND), U$2.7_VDDUSB, U$2.10_GND, U$2.12_GND, U$2.13_GND, U$2.24_GND, U$4.2 (GND); also elsewhere on the board
GPS_ON: R13.2, U$1.P54 (54_GPIO9)
ID: IC1.2 (DATA), R12.1, U$1.P50 (50_GPIO5)
JTAG_TCK: R8.2, SV2.5, U$1.P21 (21_JTAG_TCK)
JTAG_TDI: SV2.3, U$1.P12 (12JTAG_TDI)
JTAG_TDO: SV2.2, U$1.P18 (18_JTAG_TDO)
JTAG_TMS: SV2.4, U$1.P22 (22_JTAP_TMS)
LED1: U$1.P51 (51_GPIO6); also elsewhere on the board
LED2: U$1.P52 (52_GPIO7); also elsewhere on the board
LED3: U$1.P53 (53_GPIO8); also elsewhere on the board
unnamed: C17.1, C18.1, JP3.2, U$4.1 (IN)
unnamed: C13.1, T1.1 (D), U$2.22_V_BCKP, U$2.23_VCC
unnamed: R13.1, T1.3 (G)
NRST: R1.1, SV2.9, U$1.P35 (35_N_RESET)
RX1: U$1.P8 (8_GPIO17), U$2.20_TXD1
RXD: SV2.7, U$1.P47 (47_GPO2)
SCL: R5.1, U$1.P9 (9_GPIO12); also elsewhere on the board
SDA: R4.1, U$1.P10 (10_GPIO13); also elsewhere on the board
SD_CARD_DET: U$1.P11 (11_GPIO22); also elsewhere on the board
SD_CLK: U$1.P3 (3_GPIO10); also elsewhere on the board
SD_CMD: U$1.P4 (4_GPIO11); also elsewhere on the board
SD_CS: U$1.P5 (5_GPIO14); also elsewhere on the board
SD_DATA0: U$1.P6 (6_GPIO15); also elsewhere on the board
SOP0: R6.2, U$1.P34 (34_SOP0)
SOP1: R3.2, U$1.P24 (24_SOP1)
SOP2: R2.2, SV2.6, U$1.P23 (23_SOP2)
TIMEPULSE: U$1.P48 (48_GPIO3), U$2.3_TIMEPULSE
TX1: U$1.P7 (7_GPIO16), U$2.21_RXD1
TXD: SV2.8, U$1.P46 (46_GPIO1)
VDD: C10.1, C11.1, C12.1, C15.1, C16.1, R1.2, R4.2, R5.2, R12.2, SV2.10, T1.2 (S), U$1.P36 (36_VBAT_DCDC_ANA), U$1.P37 (37_VBAT_DCDC_PA), U$1.P40 (40_VBAT_DCDC_DIG_IO), U$4.3 (OUT); also elsewhere on the board

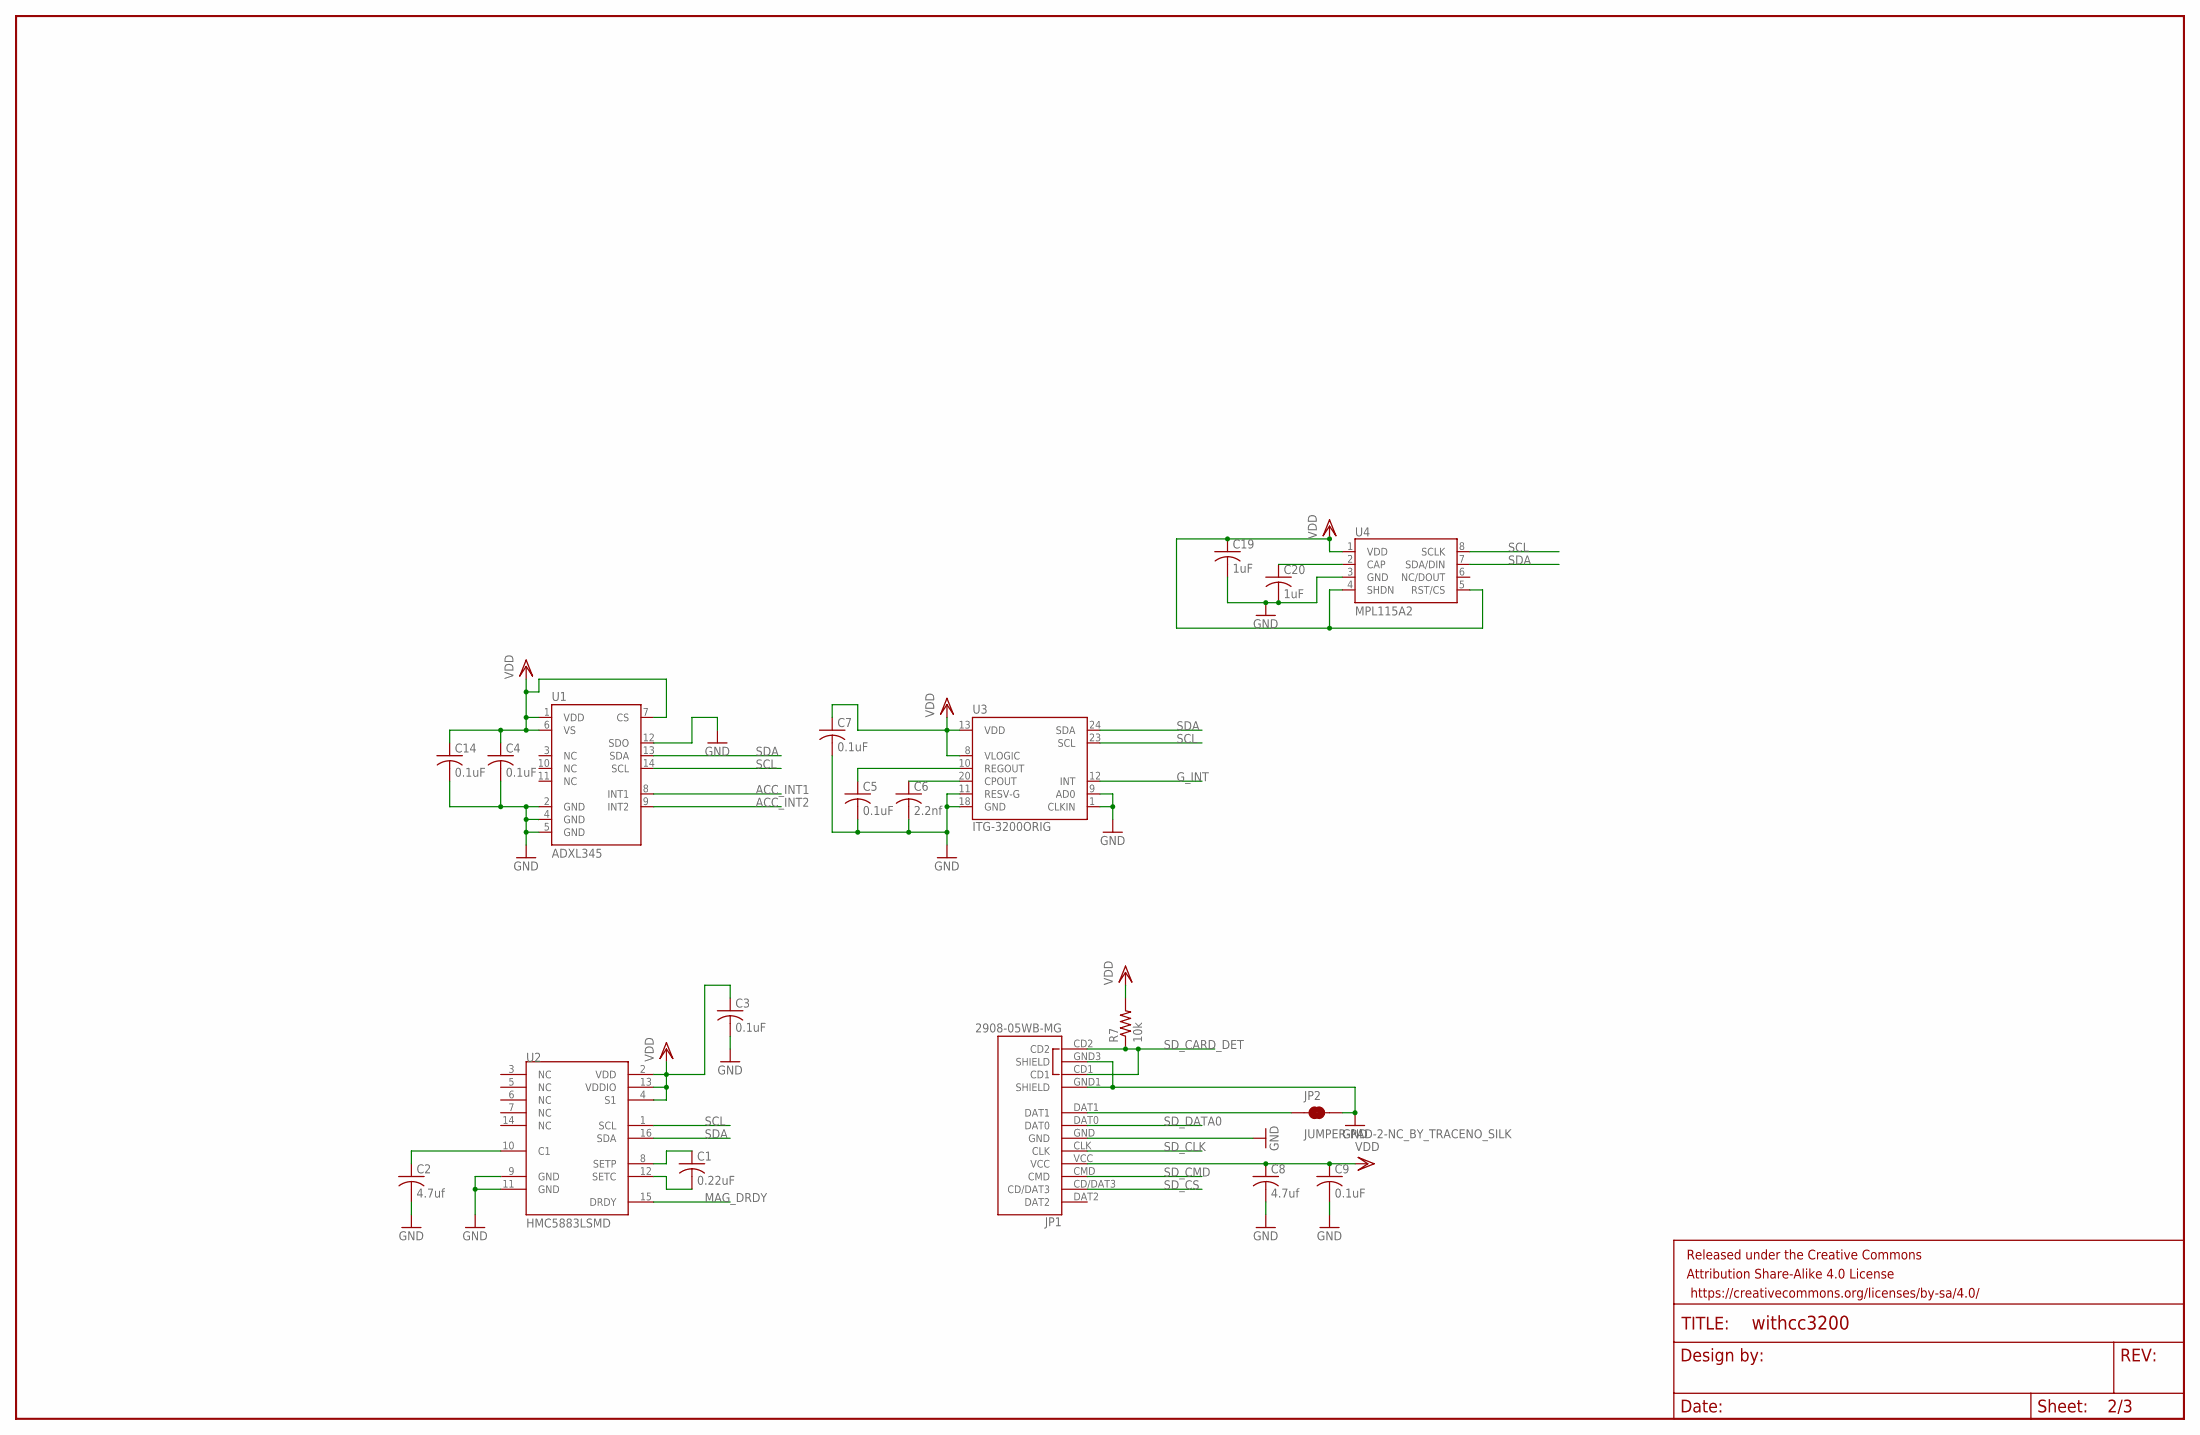
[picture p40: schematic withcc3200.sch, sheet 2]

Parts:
C1: 0.22uF; C0805K
C2, C8: 4.7uf; C0805K
C3, C4, C5, C7, C9, C14: 0.1uF; C0805K
C6: 2.2nf; C0805K
C19, C20: 1uF; C0805K
FRAME2: FRAME-LEDGER; CREATIVE_COMMONS
JP1: 2908-05WB-MG; MICRO-SD-SOCKET-SDIO
JP2: JUMPER-PAD-2-NC_BY_TRACENO_SILK; PAD-JUMPER-2-NC_BY_TRACE_NO_SILK
R7: 10k; R0603
U1: ADXL345; LGA14
U2: HMC5883LSMD; 16LPCC
U3: ITG-3200ORIG; QFN-24
U4: MPL115A2; LGA8

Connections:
ACC_INT1: U1.8 (INT1); also elsewhere on the board
ACC_INT2: U1.9 (INT2)
GND: C2.2, C3.2, C4.2, C5.2, C6.2, C7.2, C8.2, C9.2, C14.2, C19.2, C20.2, JP1.GND, JP1.GND1 (SHIELD), JP1.GND3 (SHIELD), JP2.2, U1.2 (GND), U1.4 (GND), U1.5 (GND), U1.12 (SDO), U2.9 (GND), U2.11 (GND), U3.1 (CLKIN), U3.9 (AD0), U3.11 (RESV-G), U3.18 (GND), U4.3 (GND); also elsewhere on the board
G_INT: U3.12 (INT)
MAG_DRDY: U2.15 (DRDY)
unnamed: JP1.DAT1, JP2.1
unnamed: C1.2, U2.12 (SETC)
unnamed: C1.1, U2.8 (SETP)
unnamed: C2.1, U2.10 (C1)
unnamed: C5.1, U3.10 (REGOUT)
unnamed: C6.1, U3.20 (CPOUT)
unnamed: C20.1, U4.2 (CAP)
SCL: U1.14 (SCL), U2.1 (SCL), U3.23 (SCL), U4.8 (SCLK); also elsewhere on the board
SDA: U1.13 (SDA), U2.16 (SDA), U3.24 (SDA), U4.7 (SDA/DIN); also elsewhere on the board
SD_CARD_DET: JP1.CD1, JP1.CD2, R7.1; also elsewhere on the board
SD_CLK: JP1.CLK; also elsewhere on the board
SD_CMD: JP1.CMD; also elsewhere on the board
SD_CS: JP1.CD/DAT3; also elsewhere on the board
SD_DATA0: JP1.DAT0; also elsewhere on the board
VDD: C3.1, C4.1, C7.1, C8.1, C9.1, C14.1, C19.1, JP1.VCC, R7.2, U1.1 (VDD), U1.6 (VS), U1.7 (CS), U2.2 (VDD), U2.4 (S1), U2.13 (VDDIO), U3.8 (VLOGIC), U3.13 (VDD), U4.1 (VDD), U4.4 (SHDN), U4.5 (RST/CS); also elsewhere on the board

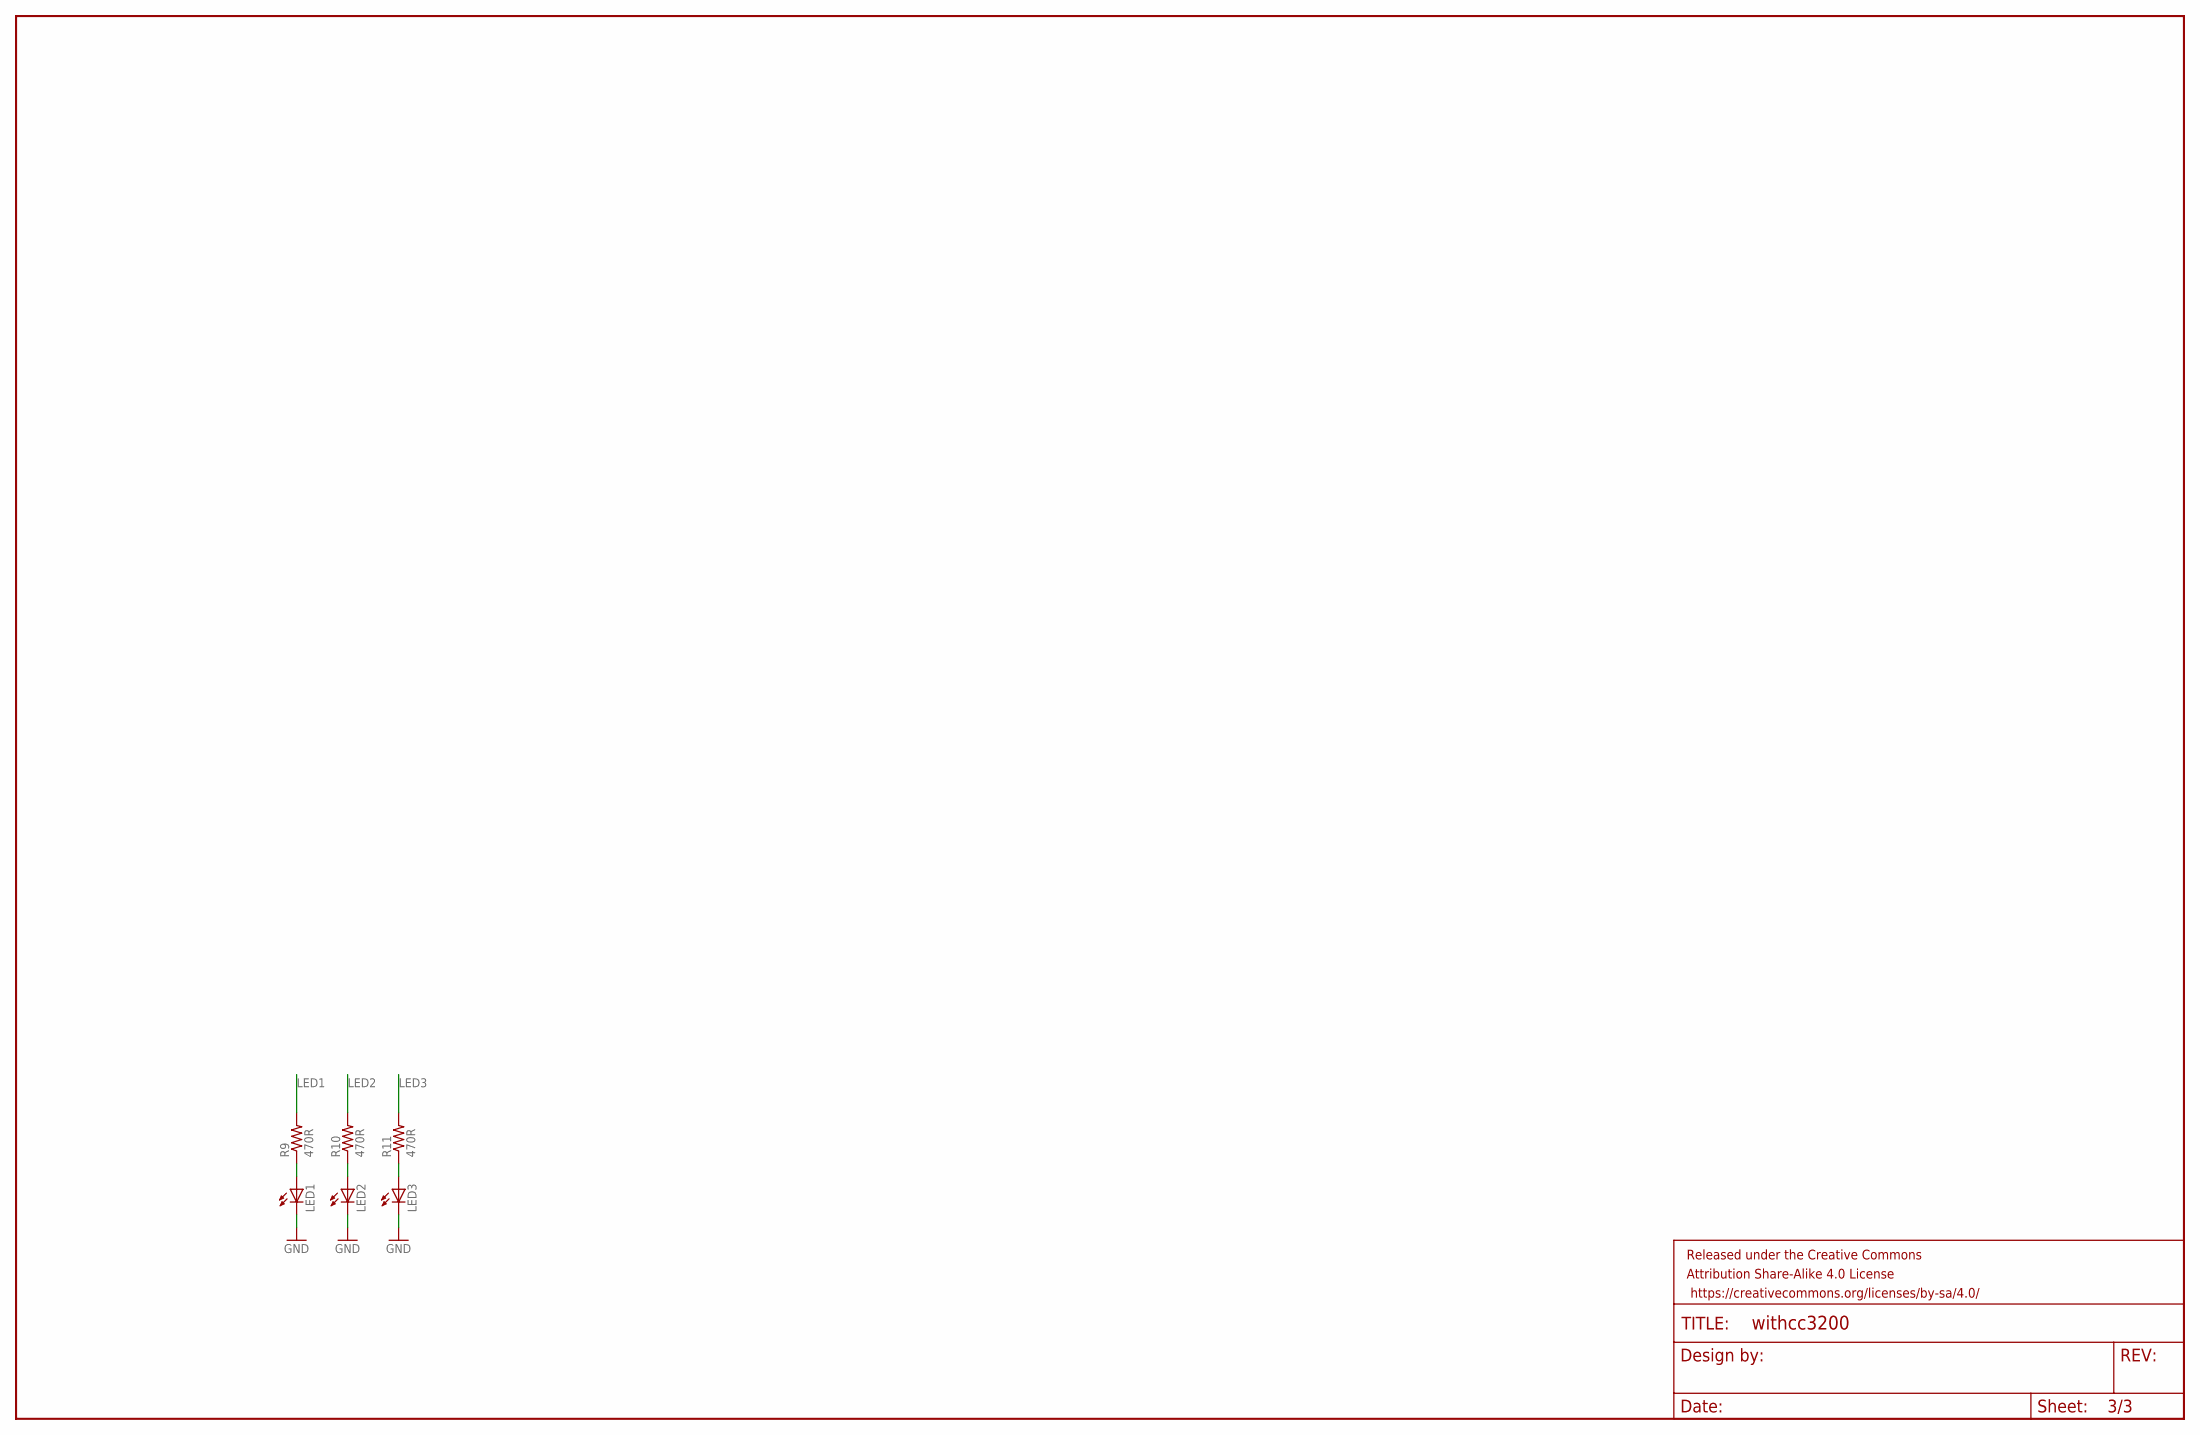
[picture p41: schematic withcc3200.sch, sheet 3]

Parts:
FRAME3: FRAME-LEDGER; CREATIVE_COMMONS
LED1, LED2, LED3: LEDCHIPLED_0805; CHIPLED_0805
R9, R10, R11: 470R; R0603

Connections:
GND: LED1.C, LED2.C, LED3.C; also elsewhere on the board
LED1: R9.2; also elsewhere on the board
LED2: R10.2; also elsewhere on the board
LED3: R11.2; also elsewhere on the board
unnamed: LED1.A, R9.1
unnamed: LED2.A, R10.1
unnamed: LED3.A, R11.1

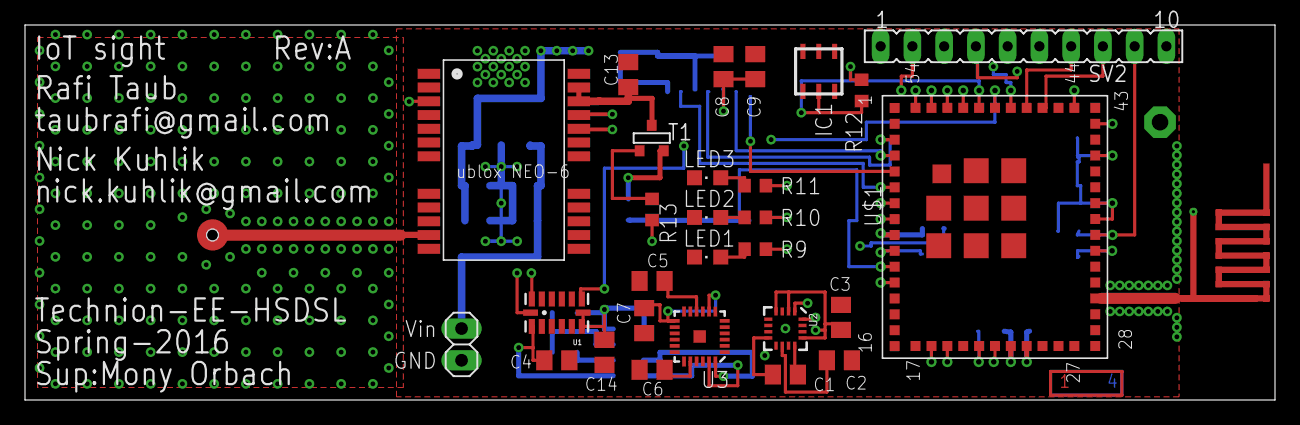
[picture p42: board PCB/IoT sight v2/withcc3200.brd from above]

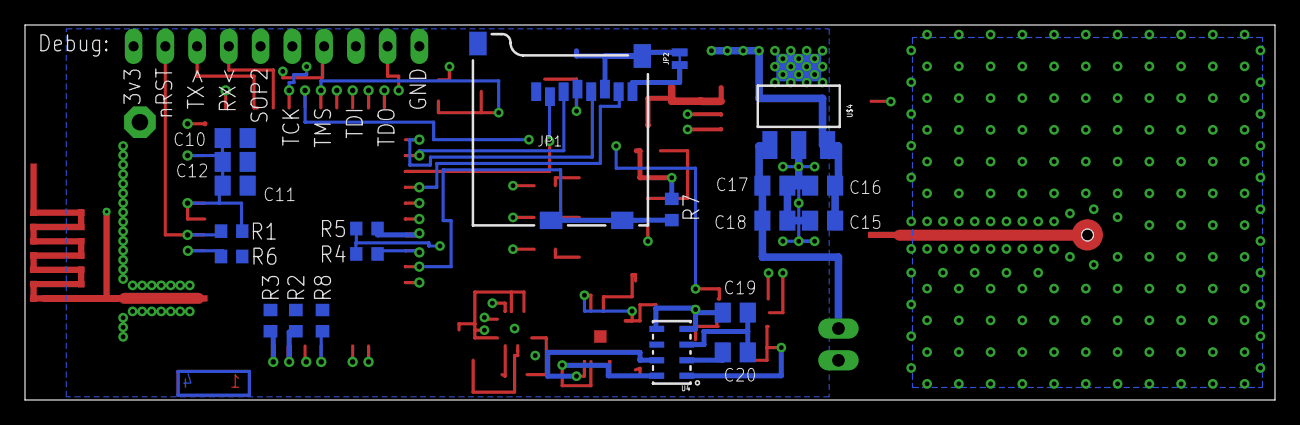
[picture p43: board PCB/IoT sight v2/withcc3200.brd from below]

Board: 4 copper layers, 100.0 x 30.0 mm, 54 parts (21 on the bottom side), 41 nets.

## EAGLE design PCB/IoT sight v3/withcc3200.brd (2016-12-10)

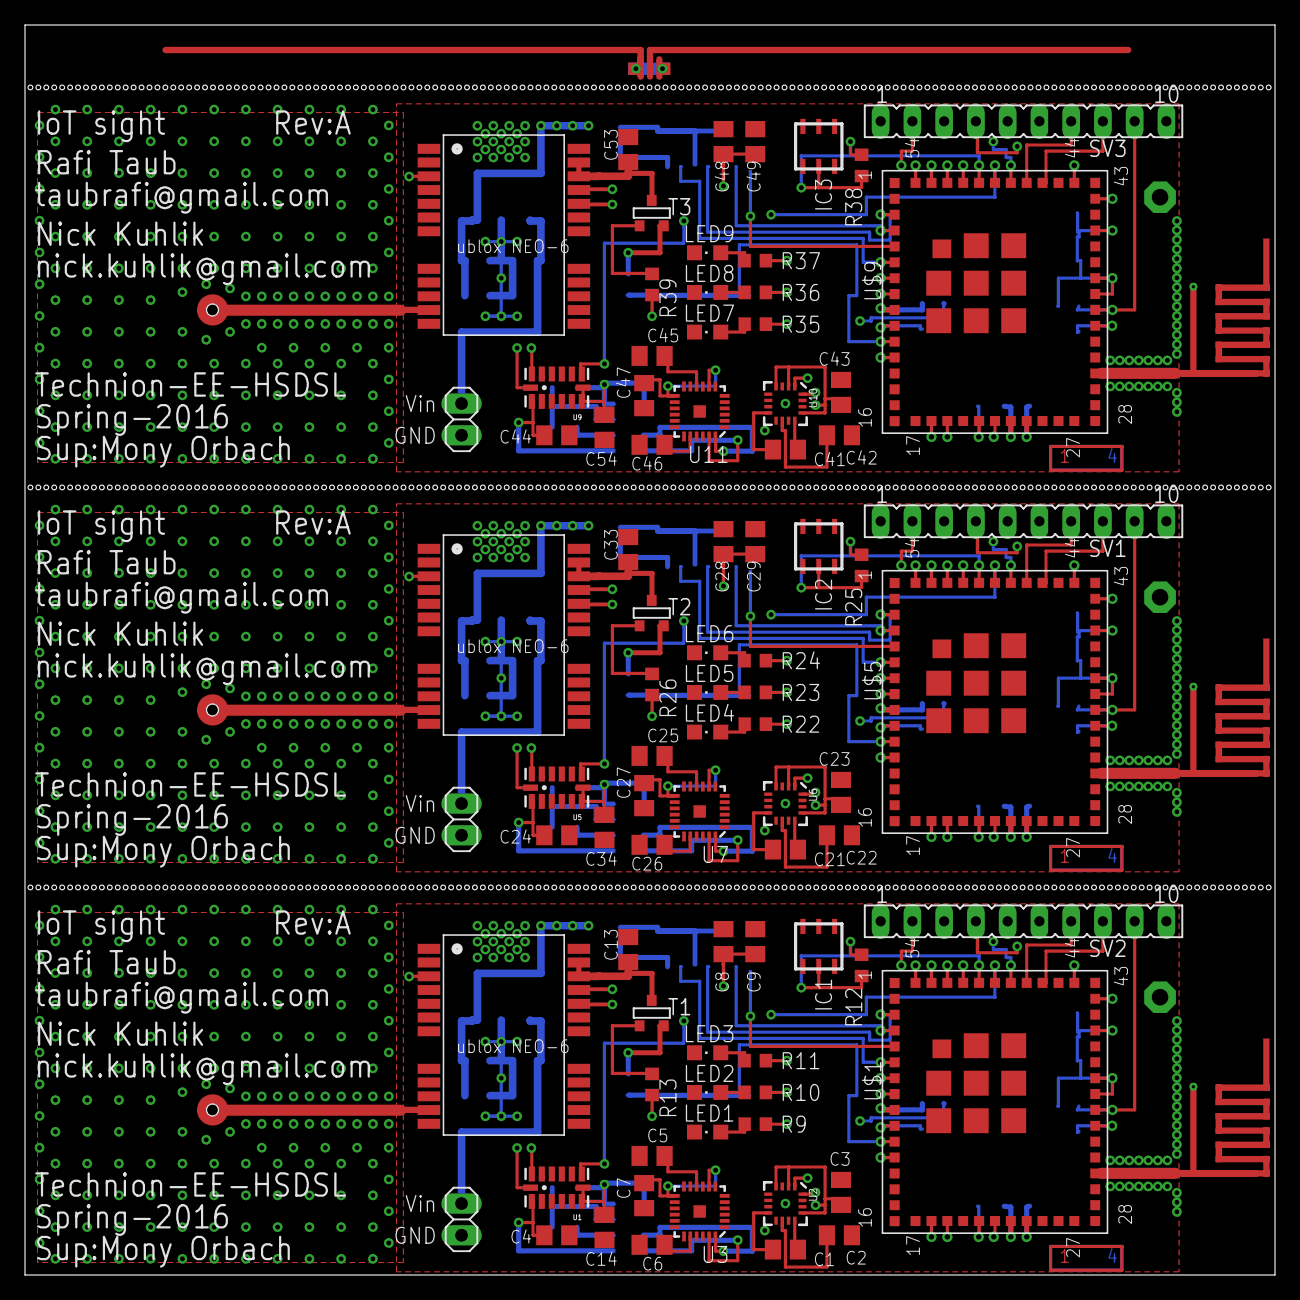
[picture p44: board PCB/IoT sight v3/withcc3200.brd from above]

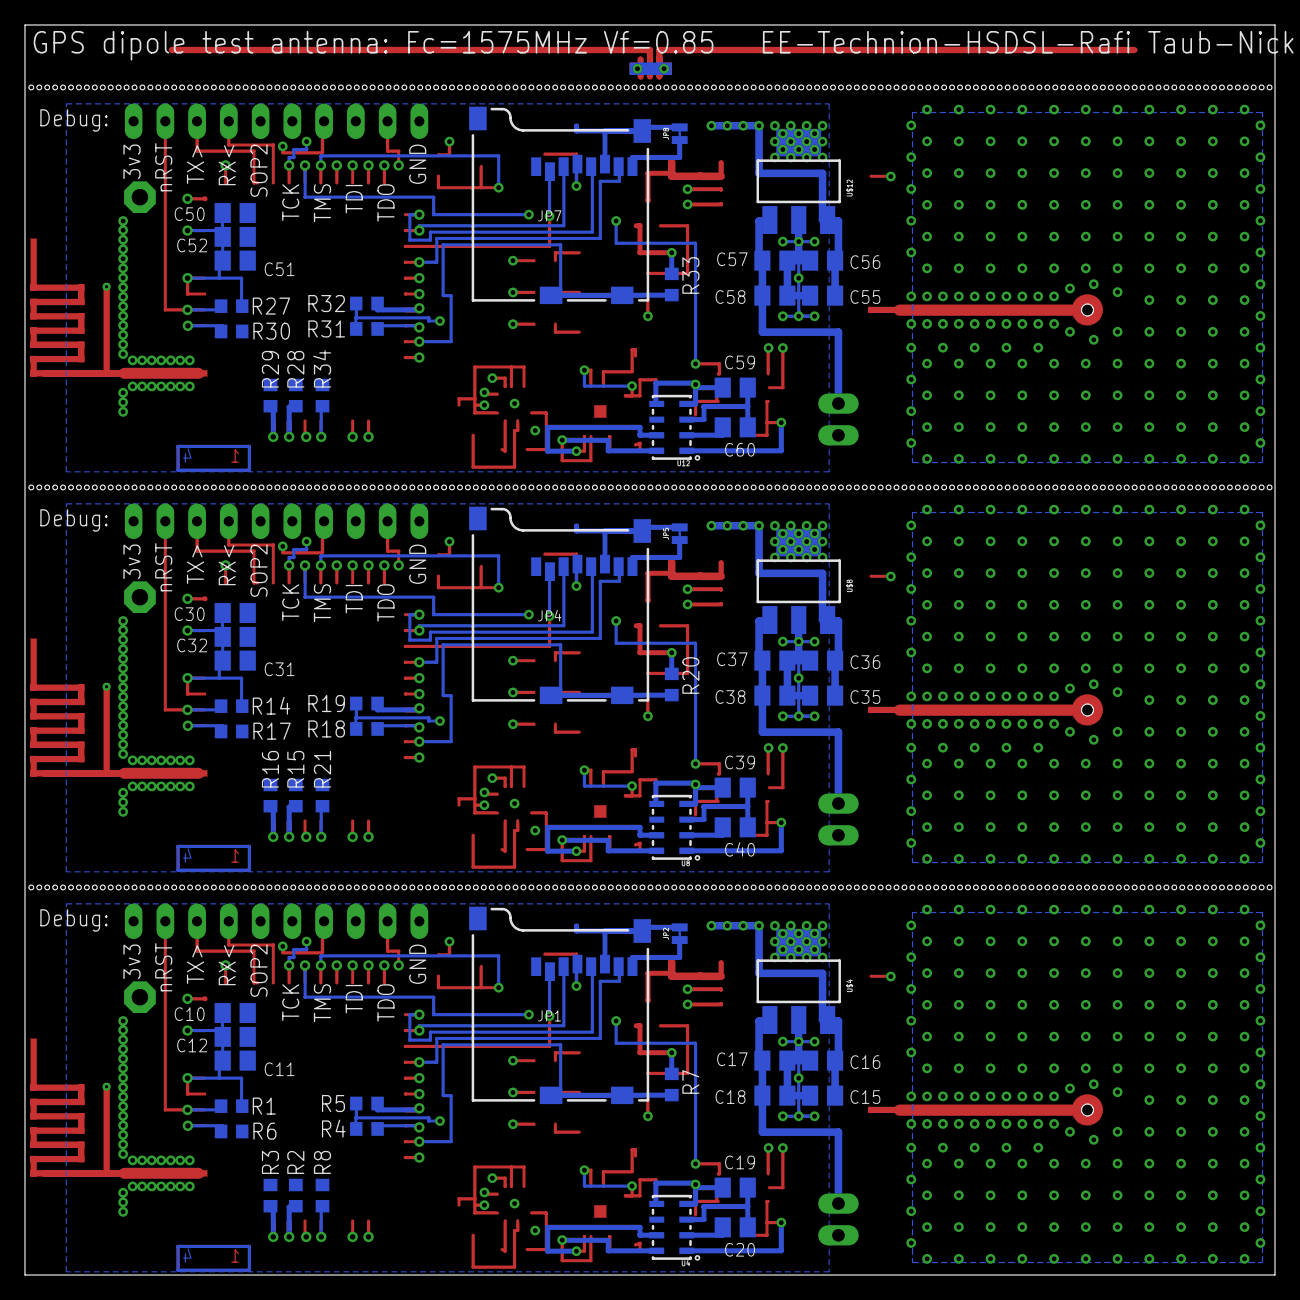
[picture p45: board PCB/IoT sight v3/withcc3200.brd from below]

Board: 4 copper layers, 100.0 x 100.0 mm, 153 parts (63 on the bottom side), 123 nets.

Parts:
ANT1, ANT2, ANT3: ADA18182; PAD-01
C1, C21, C41: 0.22uF; C0805K
C2, C8, C10, C15, C17, C22, C28, C30, C35, C37, C42, C48, C50, C55, C57: 4.7uf; C0805K
C3, C4, C5, C7, C9, C11, C13, C14, C16, C18, C23, C24, C25, C27, C29, C31, C33, C34, C36, C38, C43, C44, C45, C47, C49, C51, C53, C54, C56, C58: 0.1uF; C0805K
C6, C26, C46: 2.2nf; C0805K
C12, C32, C52: 0.01uF; C0805K
C19, C20, C39, C40, C59, C60: 1uF; C0805K
IC1, IC2, IC3: DS2401P; TSOC6
JP1, JP4, JP7: 2908-05WB-MG; MICRO-SD-SOCKET-SDIO
JP2, JP5, JP8: JUMPER-PAD-2-NC_BY_TRACENO_SILK; PAD-JUMPER-2-NC_BY_TRACE_NO_SILK
JP3, JP6, JP9: 1X02
LED1, LED2, LED3, LED4, LED5, LED6, LED7, LED8, LED9: CHIPLED_0805
R1, R7, R14, R20, R27, R33: 10k; R0603
R2, R4, R5, R12, R13, R15, R18, R19, R25, R26, R28, R31, R32, R38, R39: 2.7k; R0603
R3, R6, R8, R16, R17, R21, R29, R30, R34: 100k; R0603
R9, R10, R11, R22, R23, R24, R35, R36, R37: 470R; R0603
SV1, SV2, SV3: FE10
T1, T2, T3: BS250; SOT-23
U1, U5, U9: ADXL345; LGA14
U2, U6, U10: HMC5883LSMD; 16LPCC
U3, U7, U11: ITG-3200ORIG; QFN-24
U4, U8, U12: MPL115A2; LGA8
U$1, U$5, U$9: CC3200MOD
U$2, U$6, U$10: UBLOX_NEO-7; UBLOX_NEO-6P
U$3, U$7, U$11: FOUR_LAYER_WARNING
U$4, U$8, U$12: MIC2920A-3.3WS-TR; SOT223

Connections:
ACC_INT1: U1.8, U$1.P49
ACC_INT3: U5.8, U$5.P49
ACC_INT5: U9.8, U$9.P49
GND: ANT1.1, C2.2, C3.2, C4.2, C5.2, C6.2, C7.2, C8.2, C9.2, C10.2, C11.2, C12.2, C13.2, C14.2, C15.2, C16.2, C17.2, C18.2, C19.2, C20.2, IC1.1, JP1.GND, JP1.GND1, JP1.GND3, JP2.2, JP3.1, LED1.C, LED2.C, LED3.C, R2.1, R3.1, R6.1, R8.1, SV2.1, U1.2, U1.4, U1.5, U1.12, U2.9, U2.11, U3.1, U3.9, U3.11, U3.18, U4.3, U$1.P1, U$1.P2, U$1.P16, U$1.P27, U$1.P28, U$1.P30, U$1.P32, U$1.P38, U$1.P43, U$1.P55, U$1.P56, U$1.P57, U$1.P58, U$1.P59, U$1.P60, U$1.P61, U$1.P62, U$1.P63, U$2.7_VDDUSB, U$2.10_GND, U$2.12_GND, U$2.13_GND, U$2.24_GND, U$4.2
GND1: ANT2.1, C22.2, C23.2, C24.2, C25.2, C26.2, C27.2, C28.2, C29.2, C30.2, C31.2, C32.2, C33.2, C34.2, C35.2, C36.2, C37.2, C38.2, C39.2, C40.2, IC2.1, JP4.GND, JP4.GND1, JP4.GND3, JP5.2, JP6.1, LED4.C, LED5.C, LED6.C, R15.1, R16.1, R17.1, R21.1, SV1.1, U5.2, U5.4, U5.5, U5.12, U6.9, U6.11, U7.1, U7.9, U7.11, U7.18, U8.3, U$5.P1, U$5.P2, U$5.P16, U$5.P27, U$5.P28, U$5.P30, U$5.P32, U$5.P38, U$5.P43, U$5.P55, U$5.P56, U$5.P57, U$5.P58, U$5.P59, U$5.P60, U$5.P61, U$5.P62, U$5.P63, U$6.7_VDDUSB, U$6.10_GND, U$6.12_GND, U$6.13_GND, U$6.24_GND, U$8.2
GND2: ANT3.1, C42.2, C43.2, C44.2, C45.2, C46.2, C47.2, C48.2, C49.2, C50.2, C51.2, C52.2, C53.2, C54.2, C55.2, C56.2, C57.2, C58.2, C59.2, C60.2, IC3.1, JP7.GND, JP7.GND1, JP7.GND3, JP8.2, JP9.1, LED7.C, LED8.C, LED9.C, R28.1, R29.1, R30.1, R34.1, SV3.1, U9.2, U9.4, U9.5, U9.12, U10.9, U10.11, U11.1, U11.9, U11.11, U11.18, U12.3, U$9.P1, U$9.P2, U$9.P16, U$9.P27, U$9.P28, U$9.P30, U$9.P32, U$9.P38, U$9.P43, U$9.P55, U$9.P56, U$9.P57, U$9.P58, U$9.P59, U$9.P60, U$9.P61, U$9.P62, U$9.P63, U$10.7_VDDUSB, U$10.10_GND, U$10.12_GND, U$10.13_GND, U$10.24_GND, U$12.2
GPS_ON: R13.2, U$1.P54
GPS_ON1: R26.2, U$5.P54
GPS_ON2: R39.2, U$9.P54
ID: IC1.2, R12.1, U$1.P50
ID1: IC2.2, R25.1, U$5.P50
ID2: IC3.2, R38.1, U$9.P50
JTAG_TCK: R8.2, SV2.5, U$1.P21
JTAG_TCK1: R21.2, SV1.5, U$5.P21
JTAG_TCK2: R34.2, SV3.5, U$9.P21
JTAG_TDI: SV2.3, U$1.P12
JTAG_TDI1: SV1.3, U$5.P12
JTAG_TDI2: SV3.3, U$9.P12
JTAG_TDO: SV2.2, U$1.P18
JTAG_TDO1: SV1.2, U$5.P18
JTAG_TDO2: SV3.2, U$9.P18
JTAG_TMS: SV2.4, U$1.P22
JTAG_TMS1: SV1.4, U$5.P22
JTAG_TMS2: SV3.4, U$9.P22
LED1: R9.2, U$1.P51
LED2: R10.2, U$1.P52
LED3: R11.2, U$1.P53
LED4: R22.2, U$5.P51
LED5: R23.2, U$5.P52
LED6: R24.2, U$5.P53
LED7: R35.2, U$9.P51
LED8: R36.2, U$9.P52
LED9: R37.2, U$9.P53
unnamed: JP1.DAT1, JP2.1
unnamed: C1.2, U2.12
unnamed: C1.1, U2.8
unnamed: C2.1, U2.10
unnamed: LED1.A, R9.1
unnamed: LED2.A, R10.1
unnamed: C5.1, U3.10
unnamed: LED3.A, R11.1
unnamed: C6.1, U3.20
unnamed: C17.1, C18.1, JP3.2, U$4.1
unnamed: C13.1, T1.1, U$2.22_V_BCKP, U$2.23_VCC
unnamed: R13.1, T1.3
unnamed: C20.1, U4.2
unnamed: C21.2, U6.12
unnamed: C21.1, U6.8
unnamed: C22.1, U6.10
unnamed: C25.1, U7.10
unnamed: C26.1, U7.20
unnamed: JP4.DAT1, JP5.1
unnamed: LED4.A, R22.1
unnamed: LED5.A, R23.1
unnamed: LED6.A, R24.1
unnamed: C37.1, C38.1, JP6.2, U$8.1
unnamed: C33.1, T2.1, U$6.22_V_BCKP, U$6.23_VCC
unnamed: R26.1, T2.3
unnamed: C40.1, U8.2
unnamed: C41.2, U10.12
unnamed: C41.1, U10.8
unnamed: C42.1, U10.10
unnamed: C45.1, U11.10
unnamed: C46.1, U11.20
unnamed: JP7.DAT1, JP8.1
unnamed: LED7.A, R35.1
unnamed: LED8.A, R36.1
unnamed: LED9.A, R37.1
unnamed: C57.1, C58.1, JP9.2, U$12.1
unnamed: C53.1, T3.1, U$10.22_V_BCKP, U$10.23_VCC
unnamed: R39.1, T3.3
unnamed: C60.1, U12.2
NRST: R1.1, SV2.9, U$1.P35
NRST1: R14.1, SV1.9, U$5.P35
NRST2: R27.1, SV3.9, U$9.P35
RX1: U$1.P8, U$2.20_TXD1
RX2: U$5.P8, U$6.20_TXD1
RX3: U$9.P8, U$10.20_TXD1
RXD: SV2.7, U$1.P47
RXD1: SV1.7, U$5.P47
RXD2: SV3.7, U$9.P47
SCL: R5.1, U1.14, U2.1, U3.23, U4.8, U$1.P9
SCL1: R19.1, U5.14, U6.1, U7.23, U8.8, U$5.P9
SCL2: R32.1, U9.14, U10.1, U11.23, U12.8, U$9.P9
SDA: R4.1, U1.13, U2.16, U3.24, U4.7, U$1.P10
SDA1: R18.1, U5.13, U6.16, U7.24, U8.7, U$5.P10
SDA2: R31.1, U9.13, U10.16, U11.24, U12.7, U$9.P10
SD_CARD_DET: JP1.CD1, JP1.CD2, R7.1, U$1.P11
SD_CARD_DET1: JP4.CD1, JP4.CD2, R20.1, U$5.P11
SD_CARD_DET2: JP7.CD1, JP7.CD2, R33.1, U$9.P11
SD_CLK: JP1.CLK, U$1.P3
SD_CLK1: JP4.CLK, U$5.P3
SD_CLK2: JP7.CLK, U$9.P3
SD_CMD: JP1.CMD, U$1.P4
SD_CMD1: JP4.CMD, U$5.P4
SD_CMD2: JP7.CMD, U$9.P4
SD_CS: JP1.CD/DAT3, U$1.P5
SD_CS1: JP4.CD/DAT3, U$5.P5
SD_CS2: JP7.CD/DAT3, U$9.P5
SD_DATA0: JP1.DAT0, U$1.P6
SD_DATA1: JP4.DAT0, U$5.P6
SD_DATA2: JP7.DAT0, U$9.P6
SOP0: R6.2, U$1.P34
SOP1: R3.2, U$1.P24
SOP2: R2.2, SV2.6, U$1.P23
SOP3: R17.2, U$5.P34
SOP4: R16.2, U$5.P24
SOP5: R15.2, SV1.6, U$5.P23
SOP6: R30.2, U$9.P34
SOP7: R29.2, U$9.P24
SOP8: R28.2, SV3.6, U$9.P23
TIMEPULSE: U$1.P48, U$2.3_TIMEPULSE
TIMEPULSE1: U$5.P48, U$6.3_TIMEPULSE
TIMEPULSE2: U$9.P48, U$10.3_TIMEPULSE
TX1: U$1.P7, U$2.21_RXD1
TX2: U$5.P7, U$6.21_RXD1
TX3: U$9.P7, U$10.21_RXD1
TXD: SV2.8, U$1.P46
TXD1: SV1.8, U$5.P46
TXD2: SV3.8, U$9.P46
VDD: C3.1, C4.1, C7.1, C8.1, C9.1, C10.1, C11.1, C12.1, C14.1, C15.1, C16.1, C19.1, JP1.VCC, R1.2, R4.2, R5.2, R7.2, R12.2, SV2.10, T1.2, U1.1, U1.6, U1.7, U2.2, U2.4, U2.13, U3.8, U3.13, U4.1, U4.4, U4.5, U$1.P36, U$1.P37, U$1.P40, U$4.3
VDD1: C23.1, C24.1, C27.1, C28.1, C29.1, C30.1, C31.1, C32.1, C34.1, C35.1, C36.1, C39.1, JP4.VCC, R14.2, R18.2, R19.2, R20.2, R25.2, SV1.10, T2.2, U5.1, U5.6, U5.7, U6.2, U6.4, U6.13, U7.8, U7.13, U8.1, U8.4, U8.5, U$5.P36, U$5.P37, U$5.P40, U$8.3
VDD2: C43.1, C44.1, C47.1, C48.1, C49.1, C50.1, C51.1, C52.1, C54.1, C55.1, C56.1, C59.1, JP7.VCC, R27.2, R31.2, R32.2, R33.2, R38.2, SV3.10, T3.2, U9.1, U9.6, U9.7, U10.2, U10.4, U10.13, U11.8, U11.13, U12.1, U12.4, U12.5, U$9.P36, U$9.P37, U$9.P40, U$12.3

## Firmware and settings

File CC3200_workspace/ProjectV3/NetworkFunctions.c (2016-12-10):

/*
 * NetworkFunctions.c
 *
 *  Created on: Jun 16, 2016
 *      Author: Rafi
 */

#include "NetworkFunctions.h"
#include "includes.h"


volatile unsigned long  g_ulStatus = 0;//SimpleLink Status
unsigned long  g_ulDestinationIP; // IP address of destination server
unsigned long  g_ulGatewayIP = 0; //Network Gateway IP address
unsigned char  g_ucConnectionSSID[SSID_LEN_MAX+1]; //Connection SSID
unsigned char  g_ucConnectionBSSID[BSSID_LEN_MAX]; //Connection BSSID
unsigned char g_buff[MAX_BUFF_SIZE+1];
long bytesReceived = 0; // variable to store the file size

//*****************************************************************************
//
//! \brief This function initializes the application variables
//!
//! \param    None
//!
//! \return None
//!
//*****************************************************************************
void InitializeAppVariables()
{
	g_ulStatus = 0;
	g_ulGatewayIP = 0;
	memset(g_ucConnectionSSID,0,sizeof(g_ucConnectionSSID));
	memset(g_ucConnectionBSSID,0,sizeof(g_ucConnectionBSSID));
}


//*****************************************************************************
//! \brief This function puts the device in its default state. It:
//!           - Set the mode to STATION
//!           - Configures connection policy to Auto and AutoSmartConfig
//!           - Deletes all the stored profiles
//!           - Enables DHCP
//!           - Disables Scan policy
//!           - Sets Tx power to maximum
//!           - Sets power policy to normal
//!           - Unregister mDNS services
//!           - Remove all filters
//!
//! \param   none
//! \return  On success, zero is returned. On error, negative is returned
//*****************************************************************************
long ConfigureSimpleLinkToDefaultState()
{
	SlVersionFull   ver = {0};
	_WlanRxFilterOperationCommandBuff_t  RxFilterIdMask = {0};

	unsigned char ucVal = 1;
	unsigned char ucConfigOpt = 0;
	unsigned char ucConfigLen = 0;
	unsigned char ucPower = 0;

	long lRetVal = -1;
	long lMode = ROLE_STA;//-1;
	//UART_PRINT("\n\rHello\n\r");
	lMode = sl_Start(0, 0, 0);
	//UART_PRINT("\n\rHello2\n\r");
	ASSERT_ON_ERROR(lMode);

	// If the device is not in station-mode, try configuring it in station-mode
	if (ROLE_STA != lMode)
	{
		if (ROLE_AP == lMode)
		{
			// If the device is in AP mode, we need to wait for this event
			// before doing anything
			while(!IS_IP_ACQUIRED(g_ulStatus))
			{
#ifndef SL_PLATFORM_MULTI_THREADED
				_SlNonOsMainLoopTask();
#endif
			}
		}

		// Switch to STA role and restart
		lRetVal = sl_WlanSetMode(ROLE_STA);
		ASSERT_ON_ERROR(lRetVal);

		lRetVal = sl_Stop(0xFF);
		ASSERT_ON_ERROR(lRetVal);

		lRetVal = sl_Start(0, 0, 0);
		ASSERT_ON_ERROR(lRetVal);

		// Check if the device is in station again
		if (ROLE_STA != lRetVal)
		{
			// We don't want to proceed if the device is not coming up in STA-mode
			return DEVICE_NOT_IN_STATION_MODE;
		}
	}

	// Get the device's version-information
	ucConfigOpt = SL_DEVICE_GENERAL_VERSION;
	ucConfigLen = sizeof(ver);
	lRetVal = sl_DevGet(SL_DEVICE_GENERAL_CONFIGURATION, &ucConfigOpt,
			&ucConfigLen, (unsigned char *)(&ver));
	ASSERT_ON_ERROR(lRetVal);

	UART_PRINT("Host Driver Version: %s\n\r",SL_DRIVER_VERSION);
	UART_PRINT("Build Version %d.%d.%d.%d.31.%d.%d.%d.%d.%d.%d.%d.%d\n\r",
			ver.NwpVersion[0],ver.NwpVersion[1],ver.NwpVersion[2],ver.NwpVersion[3],
			ver.ChipFwAndPhyVersion.FwVersion[0],ver.ChipFwAndPhyVersion.FwVersion[1],
			ver.ChipFwAndPhyVersion.FwVersion[2],ver.ChipFwAndPhyVersion.FwVersion[3],
			ver.ChipFwAndPhyVersion.PhyVersion[0],ver.ChipFwAndPhyVersion.PhyVersion[1],
			ver.ChipFwAndPhyVersion.PhyVersion[2],ver.ChipFwAndPhyVersion.PhyVersion[3]);

	// Set connection policy to Auto + SmartConfig
	//      (Device's default connection policy)
	lRetVal = sl_WlanPolicySet(SL_POLICY_CONNECTION,
			SL_CONNECTION_POLICY(1, 0, 0, 0, 1), NULL, 0);
	ASSERT_ON_ERROR(lRetVal);

	// Remove all profiles
	lRetVal = sl_WlanProfileDel(0xFF);
	ASSERT_ON_ERROR(lRetVal);

	//
	// Device in station-mode. Disconnect previous connection if any
	// The function returns 0 if 'Disconnected done', negative number if already
	// disconnected Wait for 'disconnection' event if 0 is returned, Ignore
	// other return-codes
	//
	lRetVal = sl_WlanDisconnect();
	if(0 == lRetVal)
	{
		// Wait
		while(IS_CONNECTED(g_ulStatus))
		{
#ifndef SL_PLATFORM_MULTI_THREADED
			_SlNonOsMainLoopTask();
#endif
		}
	}

	// Enable DHCP client
	lRetVal = sl_NetCfgSet(SL_IPV4_STA_P2P_CL_DHCP_ENABLE,1,1,&ucVal);
	ASSERT_ON_ERROR(lRetVal);

	// Disable scan
	ucConfigOpt = SL_SCAN_POLICY(0);
	lRetVal = sl_WlanPolicySet(SL_POLICY_SCAN , ucConfigOpt, NULL, 0);
	ASSERT_ON_ERROR(lRetVal);

	// Set Tx power level for station mode
	// Number between 0-15, as dB offset from max power - 0 will set max power
	ucPower = 0;
	lRetVal = sl_WlanSet(SL_WLAN_CFG_GENERAL_PARAM_ID,
			WLAN_GENERAL_PARAM_OPT_STA_TX_POWER, 1, (unsigned char *)&ucPower);
	ASSERT_ON_ERROR(lRetVal);

	// Set PM policy to normal
	lRetVal = sl_WlanPolicySet(SL_POLICY_PM , SL_NORMAL_POLICY, NULL, 0);
	ASSERT_ON_ERROR(lRetVal);

	// Unregister mDNS services
	lRetVal = sl_NetAppMDNSUnRegisterService(0, 0);
	ASSERT_ON_ERROR(lRetVal);

	// Remove  all 64 filters (8*8)
	memset(RxFilterIdMask.FilterIdMask, 0xFF, 8);
	lRetVal = sl_WlanRxFilterSet(SL_REMOVE_RX_FILTER, (_u8 *)&RxFilterIdMask,
			sizeof(_WlanRxFilterOperationCommandBuff_t));
	ASSERT_ON_ERROR(lRetVal);


	lRetVal = sl_Stop(SL_STOP_TIMEOUT);
	ASSERT_ON_ERROR(lRetVal);

	InitializeAppVariables();

	return SUCCESS;
}



//****************************************************************************
//
//! \brief Connecting to a WLAN Accesspoint
//!
//!  This function connects to the required AP (SSID_NAME) with Security
//!  parameters specified in te form of macros at the top of this file
//!
//! \param  Status value
//!
//! \return  None
//!
//! \warning    If the WLAN connection fails or we don't aquire an IP
//!            address, It will be stuck in this function forever.
//
//****************************************************************************
long WlanConnect()
{
	SlSecParams_t secParams = {0};
	long lRetVal = 0;

	secParams.Key = (signed char *)SECURITY_KEY;
	secParams.KeyLen = strlen(SECURITY_KEY);
	secParams.Type = SECURITY_TYPE;

	lRetVal = sl_WlanConnect((signed char *)SSID_NAME,
			strlen((const char *)SSID_NAME), 0, &secParams, 0);
	ASSERT_ON_ERROR(lRetVal);

	// Wait for WLAN Event
	while((!IS_CONNECTED(g_ulStatus)) || (!IS_IP_ACQUIRED(g_ulStatus)))
	{
		// wait till connects to an AP
		_SlNonOsMainLoopTask();
	}

	return SUCCESS;

}
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

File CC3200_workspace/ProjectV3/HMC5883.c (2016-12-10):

/*
 * HMC5883.c
 *
 *  Created on: Jun 6, 2016
 *      Author: Rafi
 */

#include <string.h>
#include <stdlib.h>
#include <stdio.h>
#include <stdint.h>
#include <stdbool.h>
#include <math.h>
#include <integer.h>

#include "i2c.h"
#include "hw_memmap.h"
#include "hw_i2c.h"
#include "utils.h"
#include "i2c_if.h"

SHORT Xmcal=400, Ymcal=400, Zmcal=400;
float Xmoff=0, Ymoff=0, Zmoff=0;
float Xmax=0, Ymax=0, Zmax=0;
float Xmin=0, Ymin=0, Zmin=0;


int init_HMC5883(char addr, char cal)
{
	unsigned char data[5];
	unsigned char rdata[10];

	if(cal)
	{
		data[0] = 0x00;
		data[1] =  0x71;
		data[2] =  0xA0;//0xA0
		data[3] =  0x00;
		if(I2C_IF_Write(addr, data, 4, true) < 0) 	return -1;
		UtilsDelay(2000000); //75ms delay
		while(I2CMasterBusy(I2CA0_BASE)){}

		data[0] = 0x00;
		if(I2C_IF_Write(addr, data, 1, false)<0)	return -2;
		while(I2CMasterBusy(I2CA0_BASE)){}
		if(I2C_IF_Read(addr, rdata, 9)<0)			return -3;
		while(I2CMasterBusy(I2CA0_BASE)){}

		Xmcal = (int)rdata[3];
		Xmcal <<=8;
		Xmcal += (int)rdata[4];

		Zmcal = (int)rdata[5];
		Zmcal <<=8;
		Zmcal += (int)rdata[6];

		Ymcal = (int)rdata[7];
		Ymcal <<=8;
		Ymcal += (int)rdata[8];
	}
	else
	{
		Xmcal=400;
		Ymcal=400;
		Zmcal=400;

	}

	data[0] = 0x00;
	data[1] =  0x70;
	data[2] =  0xA0;//A0
	data[3] =  0x00;
	if(I2C_IF_Write(addr, data, 4, true) < 0)	return -4;
	while(I2CMasterBusy(I2CA0_BASE)){}
	UtilsDelay(2000000); //75ms delay

	return 0;
}



int HMC5883_read_magdata(char addr, float* Xmag, float* Ymag, float* Zmag)
{
	unsigned char data[2];
	unsigned char rdata[10];
	SHORT Xdata, Ydata, Zdata;

	data[0] = 0x00;
	if(I2C_IF_Write(addr, data, 1, false)<0)	return -1;
	while(I2CMasterBusy(I2CA0_BASE)){}
	if(I2C_IF_Read(addr, rdata, 9)<0)			return -2;
	while(I2CMasterBusy(I2CA0_BASE)){}

	Xdata = (int)rdata[3];
	Xdata <<=8;
	Xdata += (int)rdata[4];

	Zdata = (int)rdata[5];
	Zdata <<=8;
	Zdata += (int)rdata[6];

	Ydata = (int)rdata[7];
	Ydata <<=8;
	Ydata += (int)rdata[8];


	*Xmag = (float) Xdata;
	*Ymag = (float) Ydata;
	*Zmag = (float) Zdata;

	if(*Xmag>Xmax)	Xmax=*Xmag;
	if(*Ymag>Ymax)	Ymax=*Ymag;
	if(*Zmag>Zmax)	Zmax=*Zmag;

	if(*Xmag<Xmin)	Xmin=*Xmag;
	if(*Ymag<Ymin)	Ymin=*Ymag;
	if(*Zmag<Zmin)	Zmin=*Zmag;

	Xmoff = 0.5*(Xmax+Xmin);
	Ymoff = 0.5*(Ymax+Ymin);
	Zmoff = 0.5*(Zmax+Zmin);

	*Xmag -= Xmoff;
	*Ymag -= Ymoff;
	*Zmag -= Zmoff;

	*Xmag /= Xmcal;
	*Ymag /= Ymcal;
	*Zmag /= Zmcal;

	//*Zmag = 0; //Due to issue with Z-axis

	return 0;
}

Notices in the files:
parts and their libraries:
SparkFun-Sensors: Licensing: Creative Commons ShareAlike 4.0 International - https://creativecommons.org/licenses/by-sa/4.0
